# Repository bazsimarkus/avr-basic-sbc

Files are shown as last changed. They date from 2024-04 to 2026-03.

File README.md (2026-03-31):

<p align="center">
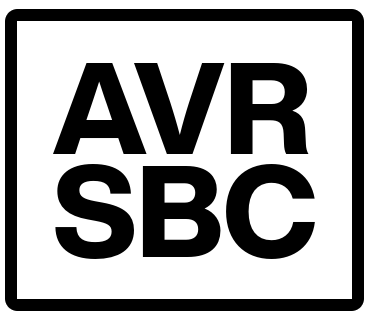
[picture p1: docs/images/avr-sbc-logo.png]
AVR-BASIC-SBC Logo
  
</p>

<h1 align="center">avr-basic-sbc</h1>

<p align="center">
  <strong>An ATmega1284P-based single board computer</strong><br>
  Composite video output &bull; PS/2 keyboard input &bull; Tiny BASIC interpreter with graphics, sound, GPIO, and serial I/O
</p>

<p align="center">
  <table align="center">
    <tr>
      <td align="center">
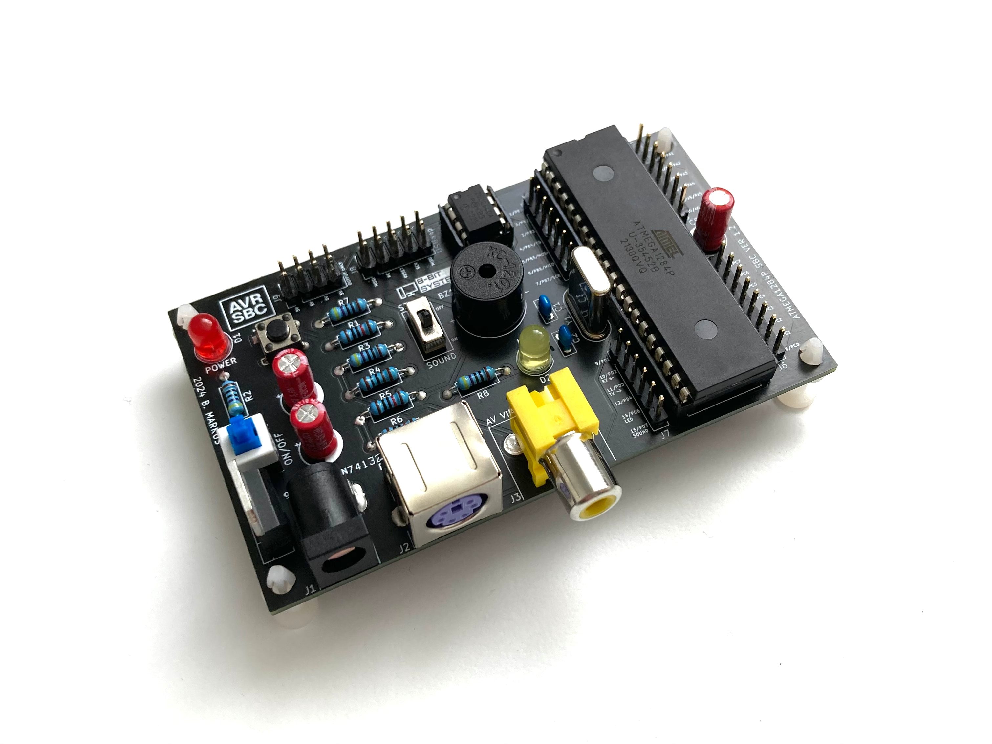
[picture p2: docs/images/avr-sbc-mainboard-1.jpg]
AVR-SBC Mainboard
        
      </td>
      <td align="center">
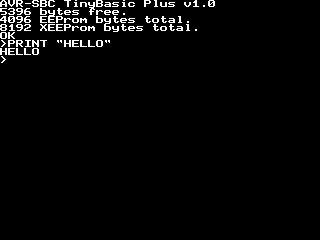
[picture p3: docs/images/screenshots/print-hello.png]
Hello World on AVR-SBC
        
      </td>
    </tr>
  </table>
</p>

---

## Table of Contents

- [Overview](#overview)
- [Features](#features)
- [Hardware](#hardware)
  - [Main Board](#main-board)
  - [Schematic](#schematic)
  - [Bill of Materials](#bill-of-materials)
  - [Pin Mapping](#pin-mapping)
- [Firmware](#firmware)
  - [Architecture](#architecture)
  - [Graphics & Video](#graphics--video)
  - [Tiny BASIC Interpreter](#tiny-basic-interpreter)
  - [Building & Flashing](#building--flashing)
- [Boomerang Shields](#boomerang-shields)
  - [Serial Boomerang Shield](#serial-boomerang-shield)
  - [Bluetooth Boomerang Shield](#bluetooth-boomerang-shield-perfboard-prototype)
  - [Seven Segment Display Extension](#seven-segment-display-extension-perfboard-prototype)
- [SBC Studio](#sbc-studio)
  - [Code Editor & Serial Upload](#code-editor--serial-upload)
  - [Bitmap Editor & Loader](#bitmap-editor--loader)
  - [MIDI to BAS Converter](#midi-to-bas-converter)
- [BASIC Examples](#basic-examples)
  - [Hello World](#hello-world)
  - [Graphics Demos](#graphics-demos)
  - [Games](#games)
  - [Sound Examples](#sound-examples)
  - [Hardware I/O Examples](#hardware-io-examples)
- [Known Limitations & Future Ideas](#known-limitations--future-ideas)
- [Personal Notes](#personal-notes)
- [Inspirations & Credits](#inspirations--credits)

---

## Overview

I always loved retrocomputing. As a kid I played around with a Commodore 64 - which I still own to this day - and I was always fascinated by the fact that computers are really just embedded systems, just nowadays unimaginably fast ones. This project grew out of that fascination.

The idea is not completely original. Many people have built similar things, and my two biggest inspirations were Jörg Wolfram's [AVR ChipBASIC](https://www.jcwolfram.de/projekte/avr/chipbasic/main.php) and Juan J. Martínez's [DAN64](https://www.usebox.net/jjm/dan64/). Neither was quite what I had in mind though - I wanted something simple to use, simple to develop for, and simple to build. A Tiny BASIC based single board computer with composite video output, a PS/2 keyboard, and some GPIO, all on a single through-hole PCB. So I decided to build my own, and here it is.

The **AVR-SBC** is an ATmega1284P-based single board computer running a Tiny BASIC interpreter. It generates a composite video signal (320×240, PAL) directly from the microcontroller, accepts input from a PS/2 keyboard, has an onboard buzzer for sound, and exposes GPIO pins for interacting with the outside world. There is also an external 25LC640 SPI EEPROM for storing programs and data - I particularly like using it to store bitmaps that can be drawn on the screen. The internal EEPROM of the ATmega1284P is available too, so a typical setup is storing a drawing program in the internal EEPROM and the actual bitmap data in the external one.

The whole thing is built with plain `avr-gcc` and `avrdude`. No Arduino framework, no dependencies - just good old C and a bit of assembly where the timing gets tight.

<p align="center">
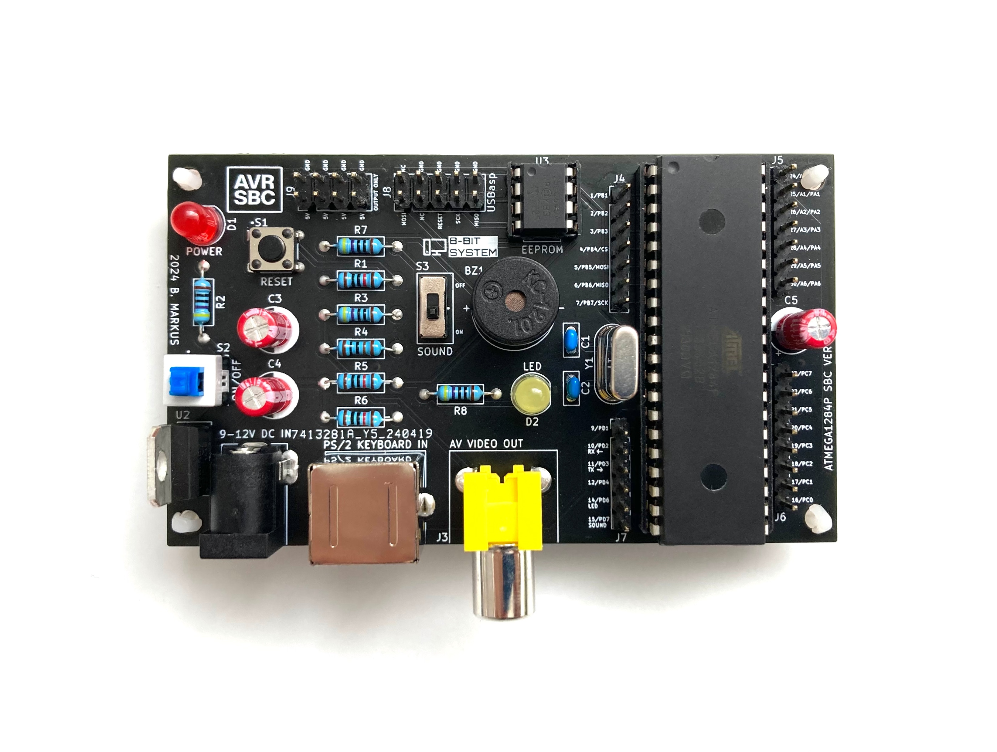
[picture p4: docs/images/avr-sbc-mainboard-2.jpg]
AVR-SBC Mainboard (alternate angle)
  
</p>

---

## Features

- **ATmega1284P** running at 16 MHz - 128 KB flash, 16 KB SRAM, 4 KB internal EEPROM
- **Composite video output** via RCA jack - 320×240 PAL, generated directly by the MCU
- **PS/2 keyboard input** - supports EN (QWERTY), DE (QWERTZ), and HU (QWERTZ) layouts, selectable at compile time
- **Tiny BASIC interpreter** - interactive prompt with 40×30 character terminal, blinking cursor, and a nice MS-DOS style 8×8 font
- **Graphics library** - pixel, line, rectangle, filled rectangle, circle, filled circle, ellipse, triangle, bitmap drawing, and more
- **Onboard piezo buzzer** - `TONE`, `TONEW`, `NOTONE` commands for playing melodies, with a slide switch to disable it
- **External 25LC640 SPI EEPROM** (8 KB) - accessible from BASIC via `XPOKE`, `XPEEK`, `XSAVE`, `XLOAD`, `XFORMAT`; great for storing bitmaps
- **Internal EEPROM** (4 KB) - accessible via `EPOKE`, `EPEEK`, `ESAVE`, `ELOAD`, `EFORMAT`
- **GPIO** - `DWRITE`, `DREAD`, `AWRITE`, `AREAD` commands using MightyCore-style pin numbering
- **UART1 serial interface** - for uploading programs from a PC via `SERLOAD`
- **Two onboard LEDs** - red power indicator, yellow user-controllable LED on PD6
- **Tactile reset button** and **power toggle switch**
- **5V regulated power** via L7805CV from a standard DC barrel jack
- **No Arduino framework** - built entirely with `avr-gcc` and `avrdude`
- **Boomerang shields** - stackable expansion boards for serial USB and Bluetooth program upload *(see [Boomerang Shields](#boomerang-shields))*
- **SBC Studio** - companion Python app for editing, uploading, bitmap conversion, and MIDI-to-BASIC conversion *(see [SBC Studio](#sbc-studio))*

---

## Hardware

### Main Board

The AVR-SBC is a fully through-hole PCB, which was a deliberate choice - it makes it easy to solder by hand and easy to modify. The board is revision **v1.2**. Versions v1.0 and v1.1 were non-working prototypes that got soldered, debugged, and eventually thrown away. The third one worked, and it has been working reliably ever since.

The heart of the board is the **ATmega1284P** in a DIP-40 socket, running off a 16 MHz HC49-U crystal. Power comes in through a standard 2.1mm DC barrel jack and is regulated to 5V by an **L7805CV** linear regulator. There are two LEDs - a red power indicator and a yellow user-controllable one on PD6. A tactile button handles reset, a toggle switch controls power, and a slide switch can disconnect the buzzer if you get tired of the beeping.

Video goes out through an RCA jack. The PS/2 keyboard connector is a right-angle Mini-DIN. There is also an external **25LC640** SPI EEPROM in a DIP-8 socket, and a 2×5 USBasp ISP programming header.

<p align="center">
  AVR-SBC Mainboard
</p>

---

### Schematic

<p align="center">
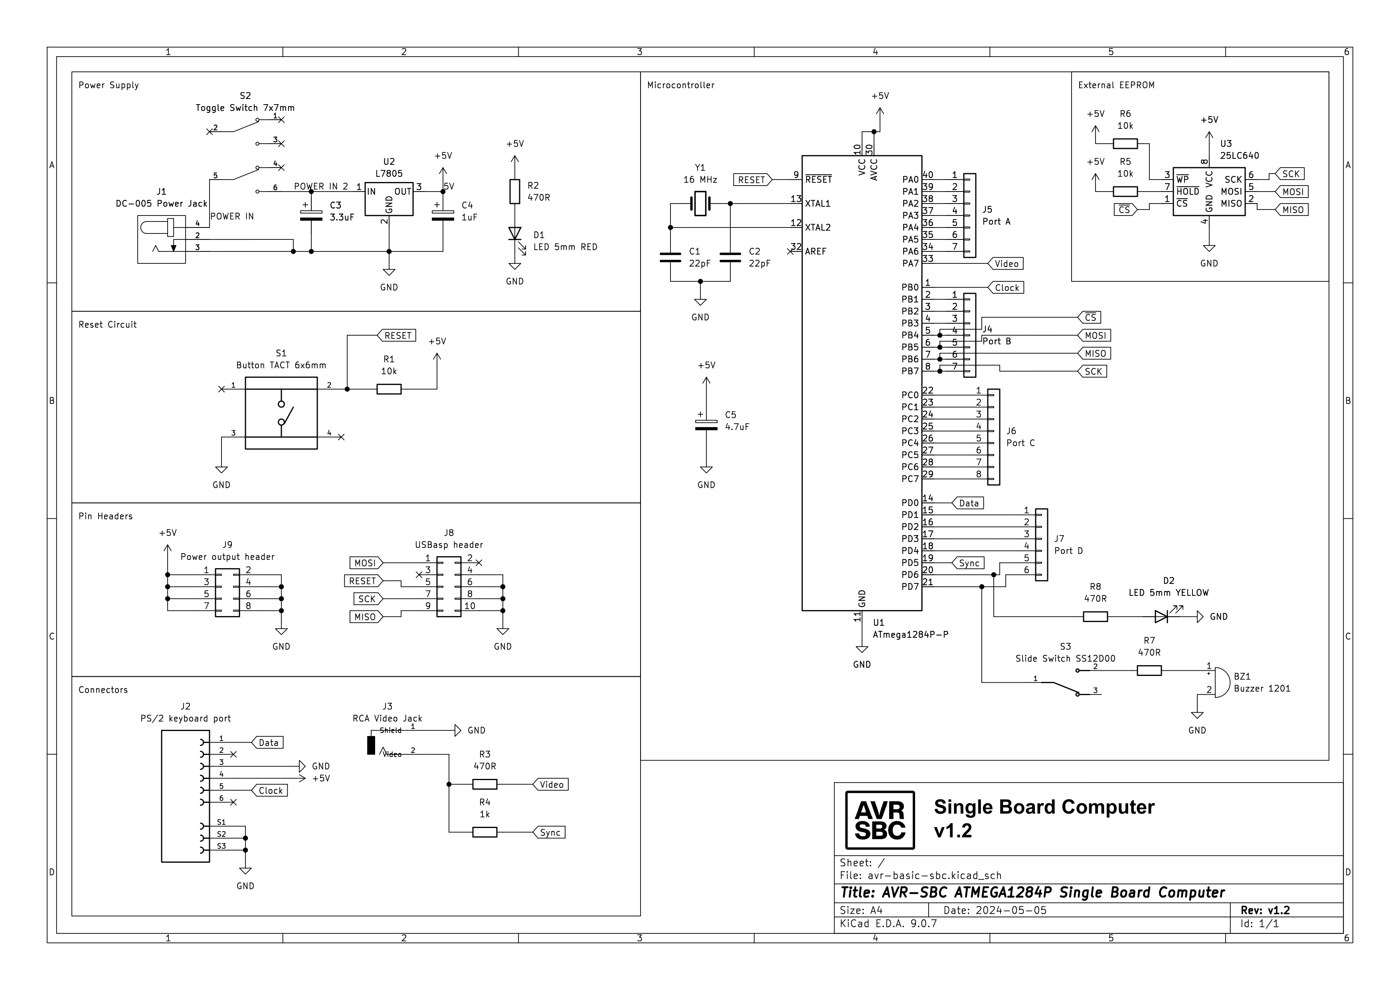
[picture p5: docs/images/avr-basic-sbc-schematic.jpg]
AVR-BASIC-SBC Schematic
  
</p>

The full KiCad project including schematic, PCB, and Gerber files is available in the `schematic/` folder.

---

### Bill of Materials

| Reference | Qty | Value / Part |
|---|-----|---|
| U1 | 1 | ATmega1284P-P (DIP-40) |
| U2 | 1 | L7805CV - 5V linear regulator (TO-220) |
| U3 | 1 | 25LC640 - SPI EEPROM 8KB (DIP-8) |
| Y1 | 1 | 16 MHz crystal (HC49-U) |
| BZ1 | 1 | Buzzer (polarized, 1201 footprint) |
| C1, C2 | 2 | 22 pF - crystal load capacitors |
| C3 | 1 | 3.3 µF electrolytic |
| C4 | 1 | 1 µF electrolytic |
| C5 | 1 | 4.7 µF electrolytic |
| D1 | 1 | LED 5mm RED - power indicator |
| D2 | 1 | LED 5mm YELLOW - user LED (PD6) |
| R1, R5, R6 | 3 | 10 kΩ |
| R2, R3, R7, R8 | 4 | 470 Ω |
| R4 | 1 | 1 kΩ |
| S1 | 1 | Tactile button 6×6mm - reset |
| S2 | 1 | Toggle switch 7×7mm - power |
| S3 | 1 | Slide switch - buzzer on/off |
| J1 | 1 | DC barrel jack 2.1mm (DC-005) |
| J2 | 1 | PS/2 keyboard connector (Mini-DIN 6) |
| J3 | 1 | RCA video jack |
| J4-J7 | 4 | Pin headers - Port B, A, C, D GPIO |
| J8 | 1 | 2×5 pin header - USBasp ISP |
| J9 | 1 | 2×4 pin header - power output |

---

### Pin Mapping

The firmware uses **MightyCore-style** pin numbering for the ATmega1284P, which is also what the BASIC `DWRITE`, `DREAD`, `AWRITE`, and `AREAD` commands expect.

| Pin | Port | Function | Available? |
|-----|---|---|---|
| 0 | PB0 | PS/2 keyboard clock | ✗ reserved |
| 1-3 | PB1-PB3 | GPIO (J4) | ✓ |
| 4-7 | PB4-PB7 | SPI - EEPROM /CS, MOSI, MISO, SCK | shared |
| 8 | PD0 | PS/2 keyboard data | ✗ reserved |
| 9 | PD1 | UART1 TX | ✓ |
| 10 | PD2 | UART1 RX | ✓ |
| 11-12 | PD3-PD4 | GPIO (J7) | ✓ |
| 13 | PD5 | Video sync output | ✗ reserved |
| 14 | PD6 | Yellow LED | ✓ |
| 15 | PD7 | Buzzer / OC2A | ✓ |
| 16-23 | PC0-PC7 | GPIO (J6) - fully free | ✓ |
| 24-30 | PA0-PA6 | GPIO (J5) - exposed on header, but see note | ⚠ see note |
| 31 | PA7 | Video data output | ✗ reserved |

> **Note on PORTA:** The high-resolution line rendering routine writes pixel data to the entire PORTA register using the AVR `OUT` instruction (1 cycle, cycle-exact timing). This means the whole port is effectively owned by the video system at runtime. The pins are physically accessible on the J5 header, but using them as GPIO will corrupt the video output. PORTC is the recommended alternative for free GPIO pins.

---

## Firmware

### Architecture

The firmware is pure C (and one assembly file), built with `avr-gcc` and flashed with `avrdude`. No Arduino framework, no HAL, no magic. Everything is wired up by hand.

The three hardware timers are each assigned a dedicated role and they all have to coexist without stepping on each other, which was honestly one of the trickier parts of getting this running:

| Timer | Role |
|---|---|
| Timer0 | 1 ms system tick (CTC mode) - used by `DELAY` and the tone duration counter |
| Timer1 | Composite video sync and scanline generation |
| Timer2 | Tone output on OC2A / PD7 - drives the buzzer via `TONE` / `TONEW` |

Memory is tight. The ATmega1284P has 16 KB of SRAM, and between the 9600-byte framebuffer (320×240 ÷ 8) and the 5500-byte BASIC program buffer, there is not much room left. It works, but there is not a lot of headroom to play with.

---

### Graphics & Video

The video output is the part I am most proud of - and the part that gave me the most trouble.

I originally used the Arduino TVout library like most similar projects do. It works, but the resolution is limited and I never really liked how it looked. I wanted 320×240, so I decided to write my own graphics library. That turned out to be a good decision, but it had consequences.

The line rendering function - `render_scanline()` in `render_line.S` - has to output one pixel every single clock cycle to hit 320 pixels per line at 16 MHz. There is simply no way to do that in C. Even a tight loop has overhead that breaks the timing. So I wrote it in AVR assembly, fully unrolled, 40 bytes × 8 bits per byte, outputting each pixel with a single `OUT` instruction directly to PORTA. No loop, no branches, just 320 consecutive `OUT` and `LSL` pairs.

The downside is that `OUT` writes to the entire port at once. That means **PORTA is permanently reserved** by the video system at runtime - the pins are physically on the J5 header, but you cannot use them as GPIO without corrupting the video output. PORTC has 8 fully free pins (J6) and is the recommended alternative. I never found a way around this limitation at 320×240, so I left it as-is. Ideas are welcome.

The graphics library (`graphics.c`) supports:

- Pixels, lines (Bresenham), horizontal and vertical lines
- Rectangles, filled rectangles, rounded rectangles
- Circles, filled circles, ellipses, filled ellipses
- Triangles, filled triangles
- Bitmap drawing from RAM or PROGMEM
- 8×8 font character rendering (MS-DOS style)
- Three draw modes: `SET`, `CLEAR`, `XOR`

The text terminal layer (`text.c`) sits on top of the graphics library and provides a 40×30 character terminal with scrolling, wrap-around, and a blinking cursor.

---

### Tiny BASIC Interpreter

The firmware is almost a direct port of **TinyBASIC**, originally written by Gordon Brandly as *68000 Tiny Basic*, then ported to C by Michael Field as *Arduino Basic*, and further developed by Scott Lawrence as *TinyBasicPlus*. I adapted it to be fully AVR C based - no Arduino framework anywhere.

On startup, the board displays a splash screen with the firmware version and available memory, then drops into the interactive `>` prompt.

<p align="center">
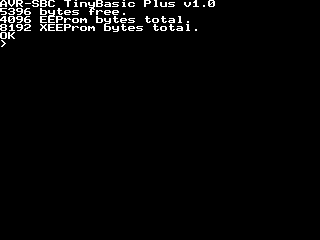
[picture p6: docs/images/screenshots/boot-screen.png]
AVR-SBC Boot Screen
  
</p>

The BASIC command set includes everything you would expect, plus a bunch of hardware-specific extensions:

#### Core Commands

| Command | Description | Example |
|---|---|---|
| `PRINT expr, expr, ...` | Prints expressions (strings or numbers) to the screen. Items separated by `,`. End with `;` to suppress newline. `?` is a shorthand alias. | `PRINT "HELLO", X` |
| `INPUT var` | Prompts the user with `?` and reads a numeric value into variable `var` (A-Z). | `INPUT A` |
| `LET var = expr` | Assigns the value of an expression to a variable (A-Z). The `LET` keyword is optional. | `LET X = 42` or `X = 42` |
| `IF expr THEN statement` | Evaluates expression; if non-zero, executes the statement after `THEN`. `THEN` is optional. Relational operators: `=`, `<>`, `!=`, `<`, `>`, `<=`, `>=`. | `IF X > 10 THEN PRINT "BIG"` |
| `GOTO expr` | Jumps to the line number given by the expression. | `GOTO 100` |
| `GOSUB expr` | Calls the subroutine at the given line number, pushing a return address onto the stack. | `GOSUB 500` |
| `RETURN` | Returns from the most recent `GOSUB` call. | `RETURN` |
| `FOR var = expr TO expr [STEP expr]` | Begins a counting loop. Variable iterates from start to end value. `STEP` defaults to 1 if omitted. | `FOR I = 1 TO 10 STEP 2` |
| `NEXT var` | Advances the `FOR` loop variable and branches back if the loop has not finished. | `NEXT I` |
| `END` | Stops program execution and returns to the prompt. | `END` |
| `STOP` | Same as `END` - stops program execution. | `STOP` |
| `REM text` | Comment line; everything after `REM` (or `'`) is ignored. | `REM THIS IS A COMMENT` |

#### Program Management

| Command | Description | Example |
|---|---|---|
| `RUN` | Executes the stored program from the first line. | `RUN` |
| `LIST [linenum]` | Lists the stored program. If a line number is given, listing starts from that line. | `LIST` or `LIST 100` |
| `NEW` | Erases the stored program from memory. | `NEW` |
| `LOAD` | Loads a program (stub - unimplemented on this platform). | `LOAD` |
| `SAVE` | Saves a program (stub - unimplemented on this platform). | `SAVE` |
| `CHAIN` | Loads a program and auto-runs it after loading (stub - unimplemented on this platform). | `CHAIN` |
| `MEM` | Prints the number of free BASIC program bytes and EEPROM usage statistics. | `MEM` |
| `BYE` | Exits the BASIC interpreter. | `BYE` |

#### GPIO

| Command | Description | Example |
|---|---|---|
| `DWRITE pin, value` | Sets a digital GPIO pin HIGH or LOW. Value can be `HIGH`/`HI`, `LOW`/`LO`, or a numeric expression (0/1). Uses MightyCore pin numbering. | `DWRITE 14, 1` |
| `AWRITE pin, value` | Writes an analog (PWM) value to a GPIO pin. Same syntax as `DWRITE`. | `AWRITE 14, 128` |
| `DREAD(pin)` | Function - reads a digital pin and returns 1 (HIGH) or 0 (LOW). Enables the internal pull-up resistor. | `X = DREAD(16)` |
| `AREAD(pin)` | Function - reads an analog value (0-1023) from an ADC pin (pins 24-30 only). | `X = AREAD(24)` |

#### Graphics

| Command | Description | Example |
|---|---|---|
| `DRAWPIX x, y, c` | Draws a single pixel at (x, y) with draw mode `c` (0=clear, 1=set, 2=xor). | `DRAWPIX 160, 120, 1` |
| `DRAWLINE x0, y0, x1, y1, c` | Draws a line from (x0, y0) to (x1, y1) with draw mode `c`. | `DRAWLINE 0, 0, 319, 239, 1` |
| `DRAWRECT x, y, w, h, c, f` | Draws a rectangle at (x, y) with width `w` and height `h`. Outline uses draw mode `c`, fill uses draw mode `f`. Use -1 for `f` to draw outline only. | `DRAWRECT 10, 10, 50, 30, 1, 1` |
| `DRAWCIRC cx, cy, r, c, f` | Draws a circle centered at (cx, cy) with radius `r`. Outline uses draw mode `c`, fill uses draw mode `f`. Use -1 for `f` to draw outline only. | `DRAWCIRC 160, 120, 40, 1, 0` |
| `DRAWCHAR x, y, char` | Draws a single 8×8 character at pixel position (x, y). The character is the literal next character in the source. | `DRAWCHAR 10, 10, A` |
| `GETPIX x, y` | Prints the pixel value (0 or 1) at position (x, y) to the screen. | `GETPIX 100, 50` |
| `CLS` | Clears the entire screen and resets the text cursor. | `CLS` |

#### Sound

| Command | Description | Example |
|---|---|---|
| `TONE freq, duration` | Starts playing a tone at `freq` Hz for `duration` ms on the buzzer. Execution continues immediately. | `TONE 440, 500` |
| `TONEW freq, duration` | Plays a tone at `freq` Hz for `duration` ms and **waits** until the tone finishes before continuing. | `TONEW 440, 500` |
| `NOTONE` | Immediately stops any tone currently playing. | `NOTONE` |

#### Timing

| Command | Description | Example |
|---|---|---|
| `DELAY expr` | Pauses execution for the given number of milliseconds. Breakable with ESC or Ctrl-C. | `DELAY 1000` |

#### Internal EEPROM (4 KB)

| Command | Description | Example |
|---|---|---|
| `ESAVE` | Saves the current program to internal EEPROM. | `ESAVE` |
| `ELOAD` | Loads a program from internal EEPROM into RAM. | `ELOAD` |
| `ELIST` | Lists the contents of the internal EEPROM to the screen. | `ELIST` |
| `EFORMAT` | Erases the entire internal EEPROM (fills with zeros). | `EFORMAT` |
| `EPOKE value, addr` | Writes `value` (byte) to internal EEPROM at address `addr`. | `EPOKE 65, 0` |
| `EPEEK var, addr` | Reads a byte from internal EEPROM at address `addr` into variable `var` (A-Z). | `EPEEK A, 0` |

#### External EEPROM (8 KB - 25LC640)

| Command | Description | Example |
|---|---|---|
| `XSAVE` | Saves the current program to external SPI EEPROM. | `XSAVE` |
| `XLOAD` | Loads a program from external EEPROM into RAM. | `XLOAD` |
| `XLIST` | Lists the contents of the external EEPROM to the screen. | `XLIST` |
| `XFORMAT` | Erases the entire external EEPROM (fills with zeros). | `XFORMAT` |
| `XPOKE value, addr` | Writes `value` (byte) to external EEPROM at address `addr`. | `XPOKE 65, 0` |
| `XPEEK var, addr` | Reads a byte from external EEPROM at address `addr` into variable `var` (A-Z). | `XPEEK A, 0` |

#### Serial (UART1)

| Command | Description | Example |
|---|---|---|
| `SEROPEN` | Opens UART1 at 9600 baud for serial communication. | `SEROPEN` |
| `SERCLOSE` | Closes UART1. | `SERCLOSE` |
| `SERPRINT expr, expr, ...` | Sends expressions (strings or numbers) over UART1. Same syntax as `PRINT`. | `SERPRINT "HELLO"` |
| `SERREAD` | Reads and displays characters from UART1 until a newline or 5-second timeout. | `SERREAD` |
| `SERLOAD` | Loads a BASIC program from UART1 into RAM (used for PC upload via SBC Studio). | `SERLOAD` |

#### Miscellaneous

| Command | Description | Example |
|---|---|---|
| `INKEY var` | Non-blocking keyboard read. Stores the ASCII value of the pressed key into variable `var` (A-Z), or 0 if no key is pressed. | `INKEY K` |
| `RSEED expr` | Seeds the random number generator with the given value. | `RSEED 42` |
| `POKE addr, value` | Writes `value` (byte) to RAM address `addr` within the BASIC memory buffer. | `POKE 0, 65` |
| `PEEK(addr)` | Function - reads a byte from RAM address `addr` within the BASIC memory buffer. | `X = PEEK(0)` |
| `ABS(expr)` | Function - returns the absolute value of the expression. | `X = ABS(-5)` |
| `RND(expr)` | Function - returns a random integer from 0 to `expr`-1. | `X = RND(100)` |

#### Operators

| Operator | Description |
|---|---|
| `+`, `-`, `*`, `/` | Arithmetic: addition, subtraction, multiplication, integer division |
| `=`, `<>`, `!=`, `<`, `>`, `<=`, `>=` | Relational operators (return 1 if true, 0 if false) |
| `-expr` | Unary negation |
| `(expr)` | Parentheses for grouping |

#### Notes:

- Line numbers are required for stored programs (e.g. `10`, `20`, `30`). Direct commands can be typed without a line number.
- Variables: single uppercase letters `A`-`Z`, 16-bit signed integers (-32768 to 32767)
- Strings in double or single quotes: `"HELLO"` or `'HELLO'`
- Multiple statements per line separated by `:` - e.g. `10 A=1 : B=2 : PRINT A+B`
- Screen resolution: 320×240 pixels (x: 0-319, y: 0-239)
- Program RAM: 5500 bytes total
- Break execution at any time with **ESC** or **Ctrl-C**

---

### Building & Flashing

**Requirements:** `avr-gcc`, `avr-libc`, `avrdude`, and `make`. On Windows, [WinAVR](https://winavr.sourceforge.net/) or Microchip Studio works fine. On Linux/macOS, install from your package manager.

```bash
# Build with default US/English keyboard layout
make

# Build with German QWERTZ layout
make KB_LAYOUT=DE

# Build with Hungarian QWERTZ layout
make KB_LAYOUT=HU

# Flash via USBasp programmer
make flash

# Show flash / SRAM / EEPROM usage
make size
```

The Makefile also exposes feature flags if you want to disable subsystems:

```bash
# Build without tone support (frees Timer2)
make FEAT_TONES=0

# Build without external EEPROM support
make FEAT_XEEPROM=0
```

**Flashing** is done via the 2×5 USBasp ISP header (J8). One important thing to be aware of: **the 5V pin on the ISP header is not connected**. The board must be powered through the DC barrel jack before you can flash it. This was a conscious decision on v1.2 to avoid back-feeding the microcontroller through the programmer.

The default programmer in the Makefile is `usbasp`. If you use something else, change the `-c usbasp` flag in the `flash` target accordingly.

---

## Boomerang Shields

After a while, connecting an FTDI USB-serial cable to PD2 and PD3 every time I wanted to upload a program got old really fast. So I opened KiCad again and designed a small stackable expansion board - the **Boomerang Shield**.

Why boomerang? Because of the shape. It has cutouts for the crystal and capacitors, and it follows the contour of the pin headers on the main board. I didn't mean for it to look like a boomerang, it just happened that way. I didn't want to redesign it - this is already the third revision of the main board - so the name stuck.

The shields use the same 2.54mm pin headers as the main board and stack directly on top. Pin headers are also broken out on the shield itself so GPIO access is not lost.

---

### Serial Boomerang Shield

<p align="center">
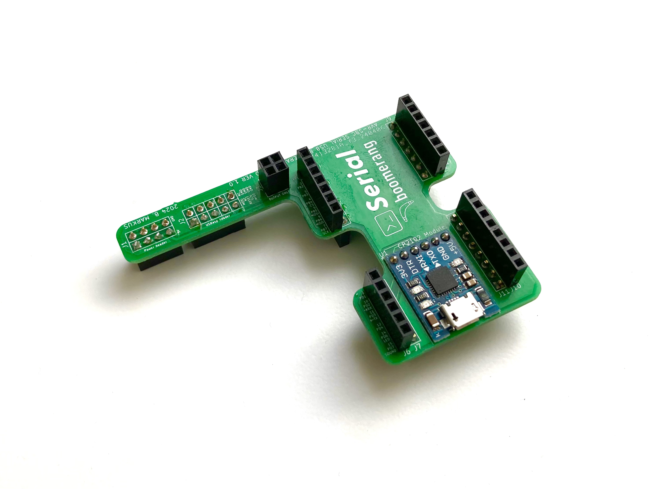
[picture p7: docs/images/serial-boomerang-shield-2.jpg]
Serial Boomerang Shield (bottom view)
  
</p>

The serial boomerang shield is the official one. It carries a **CP2102 USB-to-serial bridge module**, connects to UART1 (PD2/PD3) of the AVR-SBC, and exposes a micro-USB connector. That's it - but now I can just leave it sitting on top of the board and upload programs with a single cable. Much better.

<p align="center">
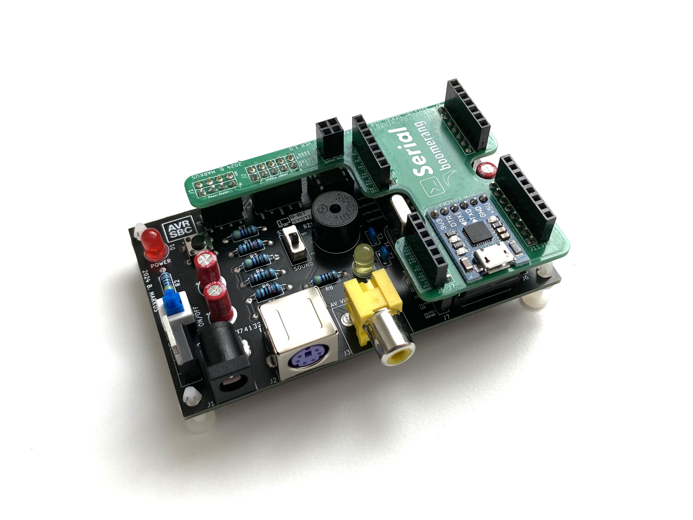
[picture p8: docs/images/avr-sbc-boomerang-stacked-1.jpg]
Serial Boomerang Shield stacked on AVR-SBC
  
</p>

The KiCad project, schematic, and Gerber files for the serial boomerang shield are in the `boomerang-shields/serial-boomerang-shield/` folder. There is also an **empty boomerang shield template** in `boomerang-shields/empty-boomerang-shield-template/` if you want to design your own expansion.

<p align="center">
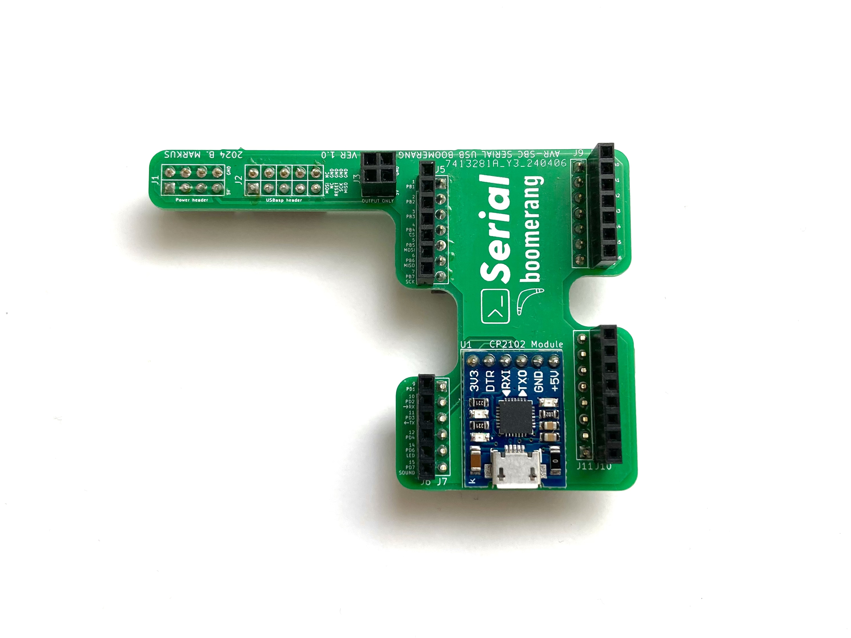
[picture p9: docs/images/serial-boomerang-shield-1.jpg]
Serial Boomerang Shield
  
</p>

---

### Bluetooth Boomerang Shield *(perfboard prototype)*

Once I had the serial shield working, I started thinking about what else could plug into the same spot. The CP2102 module and an **HC-06 Bluetooth Classic module** have a very similar pinout - both are essentially a UART bridge. So I quickly wired one up on a perfboard with the same pin header footprint as the serial shield, plugged it in, and it worked.

<p align="center">
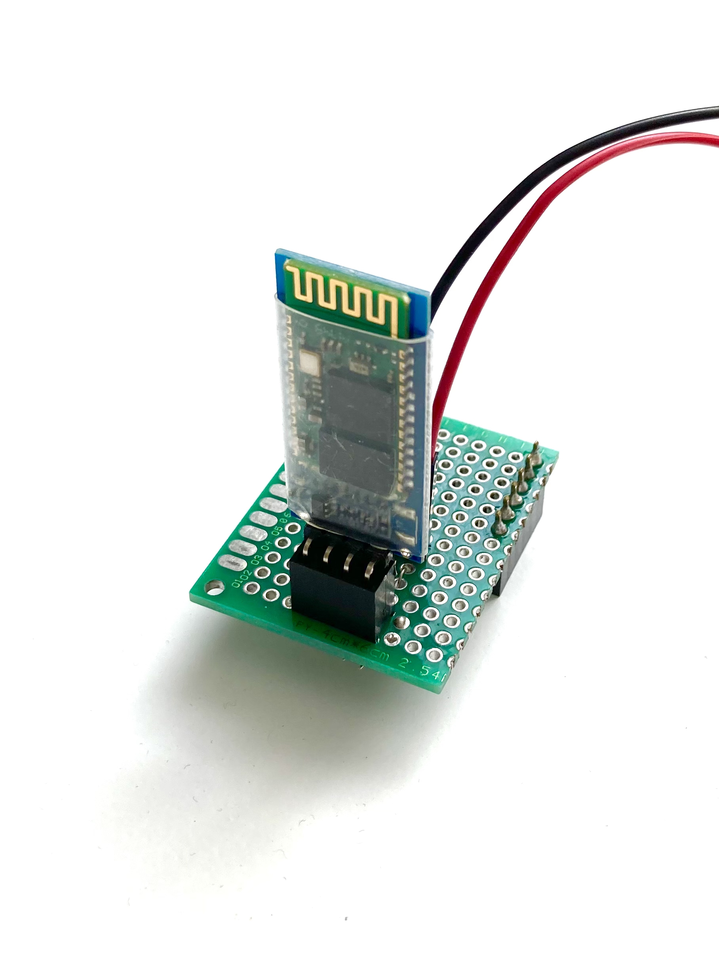
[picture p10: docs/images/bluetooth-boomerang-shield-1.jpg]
Bluetooth Boomerang Shield (perfboard prototype)
  
</p>

When the HC-06 is paired with a PC, it shows up as a virtual COM port via Bluetooth Classic SPP - exactly the same as the USB cable. That means I can upload BASIC programs to the AVR-SBC completely wirelessly. Which is, honestly, pretty amazing for a board built around an 8-bit microcontroller.

There is no official PCB design for the Bluetooth boomerang yet - it lives on a perfboard prototype for now. If I ever design it properly, I would probably use a better module, something like a Würth Elektronik Proteus-IV, a Skoll-I, or an ESP32-based module.

---

### Seven Segment Display Extension *(perfboard prototype)*

I also soldered together a small perfboard circuit with a **seven segment display** that stacks on top of the boomerang shield.

<p align="center">
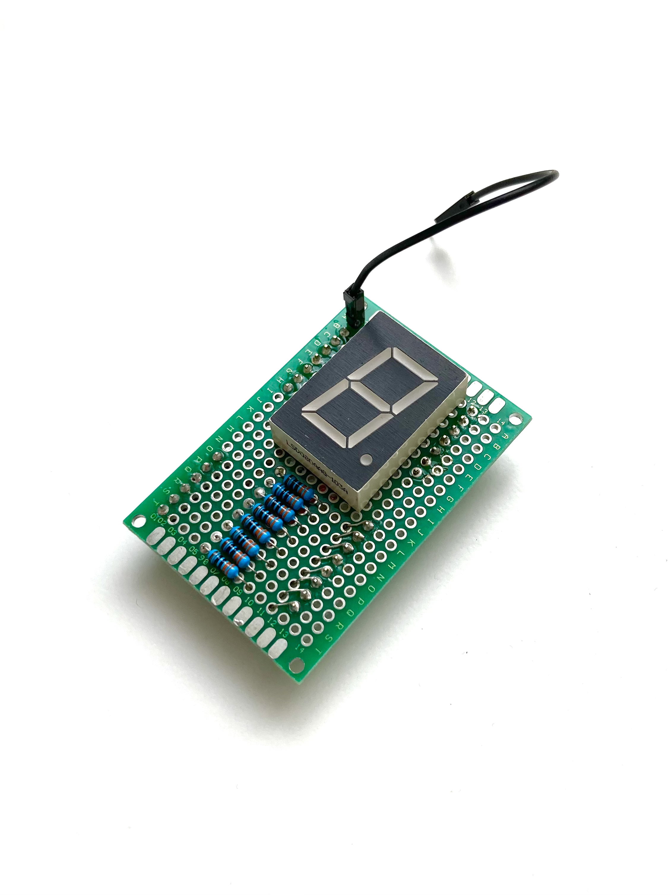
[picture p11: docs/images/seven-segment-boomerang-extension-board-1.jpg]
Seven Segment Extension Board
  
</p>

So at one point I had three layers: AVR-SBC → Serial Boomerang Shield → Seven Segment Extension. There is a BASIC example for it in the `examples/` folder.

<p align="center">
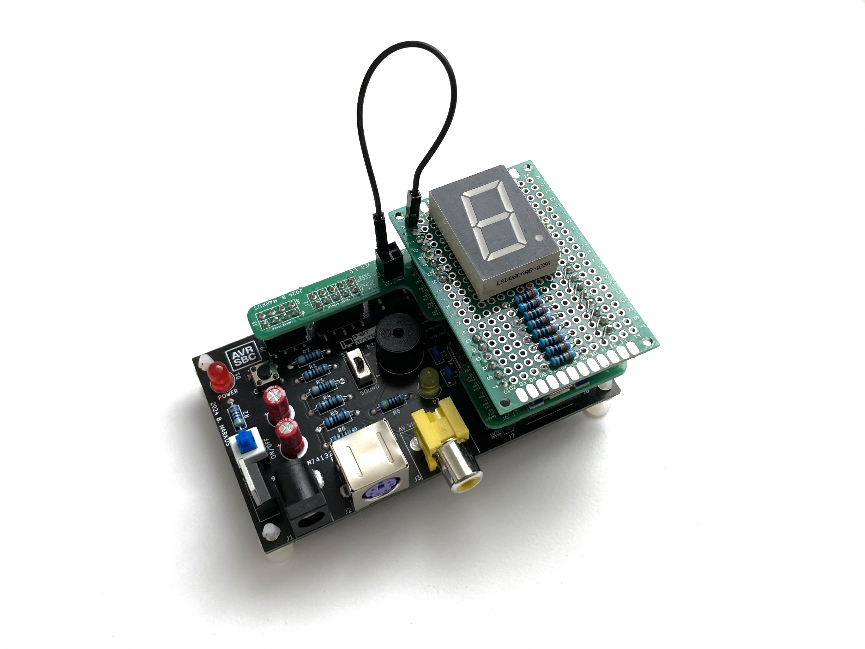
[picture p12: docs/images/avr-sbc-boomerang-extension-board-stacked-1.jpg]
All three boards stacked
  
</p>

Like the Bluetooth shield, this one never got an official PCB design. It remains a perfboard prototype.

---

## SBC Studio

SBC Studio is a companion Python application for the AVR-SBC. It started as a simple serial uploader - basically just a way to type programs into the board really fast over UART1 without having to sit at a PS/2 keyboard. Over time it grew into something more, so I gave it a proper name.

<p align="center">
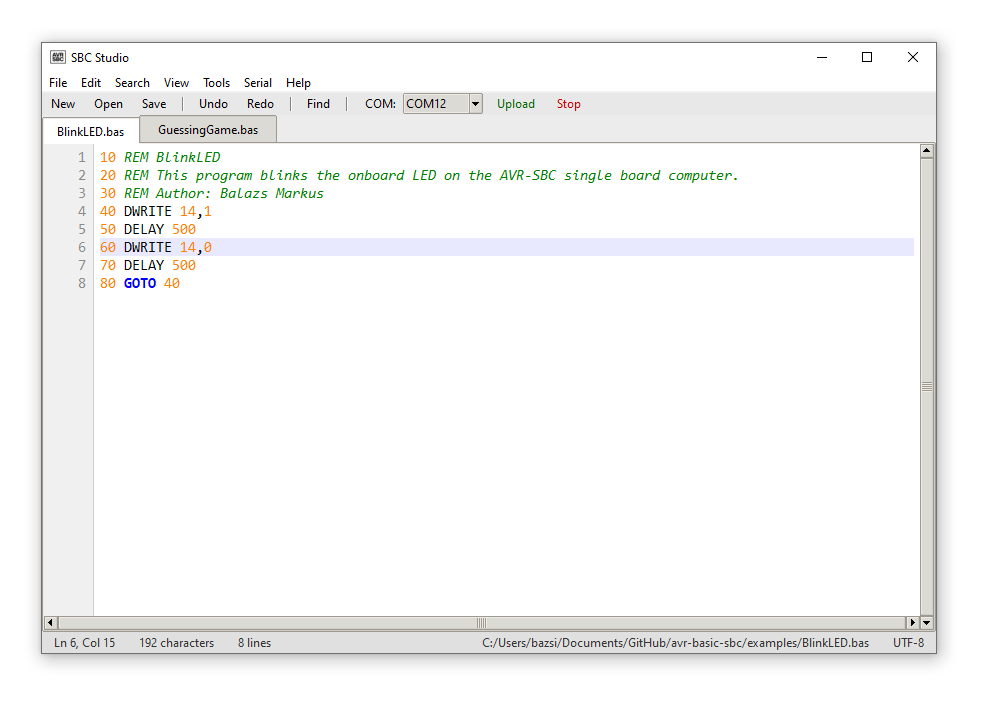
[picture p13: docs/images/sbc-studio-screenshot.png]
SBC Studio screenshot
  
</p>

It requires Python 3 with `pyserial`. The bitmap tools also need `Pillow`, and the MIDI converter needs `pretty_midi`. Everything else is standard library.

```bash
pip install pyserial Pillow pretty_midi
python sbc-studio.py
```

The source is in `pc-tools/sbc-studio/`.

---

### Code Editor & Serial Upload

The main window is a lightweight `.bas` file editor with syntax highlighting, line numbers, tab support, find & replace, and undo/redo. It is nothing fancy, but it is comfortable enough for writing and editing Tiny BASIC programs.

The serial upload works by opening UART1 at 9600 baud and sending the program character by character - essentially simulating someone typing it in at the `>` prompt, just very fast. To upload, select your COM port from the toolbar, open or write a `.bas` file, and hit upload. The board receives it line by line exactly as if you had typed it yourself.

The keyboard layout for the PS/2 side (EN/DE/HU) is selected at firmware compile time, but the upload always goes through serial so the layout doesn't matter there.

---

### Bitmap Editor & Loader

This was a fun one to build. The **Bitmap Editor** takes any image file and converts it to a 128×64 monochrome bitmap suitable for the AVR-SBC screen. It has options for scaling, centering, dithering (Floyd-Steinberg), threshold control, rotation, flip, and background colour. The output is a standard 1-bit `.bmp` file.

The **Bitmap Loader** then uploads that `.bmp` to the AVR-SBC's external 25LC640 EEPROM via serial, using `XPOKE` commands split into batches. Once uploaded, a small BASIC program reads the bitmap back out with `XPEEK` and draws it pixel by pixel with `DRAWPIX`.

<p align="center">
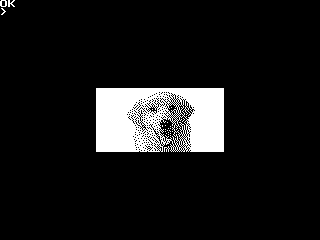
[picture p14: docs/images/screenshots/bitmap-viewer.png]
Bitmap viewer running on the AVR-SBC
  
</p>

I included two examples in `pc-tools/sbc-studio/sbc-studio-output/bitmap-editor/` - a photo of our dog and a flower.

The reason I like this so much is that the external EEPROM fits a 128×64 bitmap very comfortably, and you never have to take the chip out of the socket to reprogram it. Everything goes over serial.

---

### MIDI to BAS Converter

At some point I realised that the `TONEW` command - which plays a tone at a given frequency and waits for it to finish - maps almost perfectly onto MIDI note data. So I built a converter that takes a single-track `.mid` file, extracts the notes, calculates frequencies and durations, and outputs a `.bas` file full of `TONEW` and `DELAY` statements that the AVR-SBC can play on its onboard buzzer.

The output is capped at around 5300 bytes to fit the BASIC program buffer. It is not going to replace a proper audio system, but hearing Für Elise come out of a piezo buzzer on a board you built yourself is genuinely satisfying. Two examples are included in `pc-tools/sbc-studio/sbc-studio-output/midi-to-bas-converter/` - Für Elise and Ode to Joy.

---

## BASIC Examples

Once the board was up and running I could finally sit down and actually write some programs for it in Tiny BASIC. The examples are all in the `examples/` folder. They cover a bit of everything - games, graphics demos, sound, and hardware I/O.

All of them can be typed in at the `>` prompt directly, or uploaded from a PC using SBC Studio.

---

### Hello World

The simplest possible start. The `PRINT` command outputs text to the screen.

```basic
PRINT "HELLO"
```

<p align="center">
  Hello World on AVR-SBC
</p>

---

### Graphics Demos

The graphics library makes it easy to draw shapes directly from BASIC. These examples show off what the 320×240 display can do.

| File | Description |
|---|---|
| `ConcentricCircles.bas` | Draws concentric circles filling the screen |
| `RandomRectangles.bas` | Fills the screen with randomly placed rectangles |
| `Spirograph.bas` | Spirograph-style pattern using lines and loops |
| `StarField.bas` | Scrolling star field effect |
| `BouncingBall.bas` | A ball bouncing around the screen |

<p align="center">
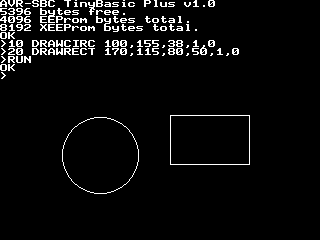
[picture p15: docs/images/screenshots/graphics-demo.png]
Graphics demo running on AVR-SBC
  
</p>

---

### Games

A few simple games that show off keyboard input, random numbers, and the graphics commands together.

| File | Description |
|---|---|
| `EatTheTargets.bas` | Move a cursor around the screen and eat targets |
| `GuessTheNumber.bas` | Classic guess the number game with hints |
| `SlotMachine.bas` | An ASCII slot machine |

---

### Sound Examples

These use the `TONE` and `TONEW` commands to play melodies on the onboard buzzer. The MIDI converter in SBC Studio was used to generate the two classical pieces.

| File | Description |
|---|---|
| `CMajorPiano.bas` | Plays a C major scale using the keyboard |
| `MelodyPlayer.bas` | A simple melody player |
| `furelise.bas` *(generated)* | Für Elise - in `pc-tools/sbc-studio/sbc-studio-output/midi-to-bas-converter/` |
| `odetojoy.bas` *(generated)* | Ode to Joy - in `pc-tools/sbc-studio/sbc-studio-output/midi-to-bas-converter/` |

---

### Hardware I/O Examples

These examples interact with the GPIO pins and show how `DWRITE`, `DREAD`, and the EEPROM commands work in practice.

| File | Description |
|---|---|
| `BlinkLED.bas` | Blinks the onboard yellow LED on PD6 using `DWRITE` |
| `SevenSegmentDisplay.bas` | Drives a seven segment display connected to PORTC |

<p align="center">
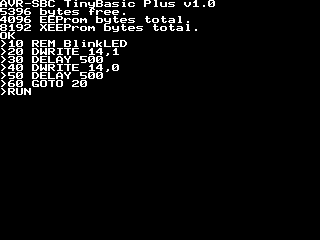
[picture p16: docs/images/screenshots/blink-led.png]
Blink LED example running on AVR-SBC
  
</p>

---

## Known Limitations & Future Ideas

The board works, and it works reliably. But it is not perfect, and I know exactly where the rough edges are.

---

### Hardware

**Decoupling capacitors** - when I designed the board I was quite casual with component choices, and I skipped the per-chip decoupling capacitors. There are bulk capacitors for the microcontroller and the L7805CV, but they are not following the reference design. If I were to redesign the board I would definitely add proper decoupling caps on every supply pin.

**No reverse polarity protection** - the DC input has no protection diode. Plugging in the barrel jack the wrong way around will likely kill the board. A simple series diode or a P-channel MOSFET would fix this.

**No Schottky diode on the ISP header** - to prevent back-feeding the microcontroller through the programmer's VCC pin, I simply left the 5V pin on the ISP header unconnected. It works, but a proper Schottky diode would be a cleaner solution. As it stands, the board must always be powered through the DC barrel jack when programming.

**PORTA reserved by the video system** - as described in the Firmware section, the cycle-exact line rendering routine writes to the entire PORTA register using the AVR `OUT` instruction. This means PA0-PA6 cannot be used as GPIO without corrupting the video output, even though the pins are physically accessible on the J5 header. Getting 320×240 resolution with proper timing while also making PORTA available as GPIO is an unsolved problem for this project. If you have an idea, I would love to hear it.

---

### Software & Features

**Boomerang shields without official PCBs** - the Bluetooth boomerang and the seven segment extension board are both perfboard prototypes. They work great but there are no KiCad files for them. At some point I would like to design proper PCBs for both - and when I do, I would probably swap the HC-06 for something more modern, like a Würth Elektronik Proteus-IV, a Skoll-I, or an ESP32-based module.

**Single-track MIDI only** - the MIDI to BAS converter in SBC Studio only handles single-track MIDI files. Multi-track files are not supported, which rules out a lot of MIDI content. Since the buzzer is monophonic anyway this is not a huge loss, but smarter track selection would be a nice improvement.

**Auto-run from EEPROM** - the firmware supports an `ENABLE_EAUTORUN` flag that automatically runs the program stored in internal EEPROM on boot, without showing the `>` prompt first. This is disabled by default but could be useful for standalone appliance-style deployments.

---

## Personal Notes

I started this project many years ago, then stopped, then restarted, then had a long pause. Many versions of KiCad were released in the meantime. AI systems started developing and becoming more and more advanced. And this project was still just there, waiting on a shelf somewhere between the other unfinished things. But occasionally when I came back to it, it made me very happy and I found it genuinely challenging.

Before this project I was usually defaulting to just using the Arduino framework - like the TVout-based firmware also did, and like many similar projects still do. But during this project I realized that with the power of real C and assembly you can get much further. Writing the line renderer in assembly, getting the timing right across three timers, squeezing everything into 16 KB of SRAM - none of that would have happened if I had stayed in Arduino land. So it was definitely a nice learning experience about myself too. Now there is no going back. Even the simplest things I do in low level C, and I have become really interested in assembly as well.

I am glad I have this project. I can't wait to see what the future brings with it - I am sure it will be exciting. And knowing myself, I will probably abandon it for a while again, and then one day come back and find something new to add. The hardware stays the same.

---

## Inspirations & Credits

### Inspiration Projects

This project would not exist without these two:

- **Jörg Wolfram** - [AVR ChipBASIC](https://www.jcwolfram.de/projekte/avr/chipbasic/main.php)
  The project that first showed me this kind of thing was possible on an AVR microcontroller.

- **Juan J. Martínez** - [DAN64](https://www.usebox.net/jjm/dan64/)
  A beautifully executed AVR-based home computer that was a big influence on the direction of this project.

---

### Tiny BASIC Lineage

The firmware interpreter is based on a long chain of ports and adaptations:

- **Gordon Brandly** - original *68000 Tiny Basic*
- **Michael Field** - ported to C as *Arduino Basic*
- **Scott Lawrence** - extended and maintained as [TinyBasicPlus](https://github.com/BleuLlama/TinyBasicPlus)

The AVR-SBC version is a bare-metal port of TinyBasicPlus, adapted for the ATmega1284P with no Arduino framework and extended with graphics, sound, EEPROM, and serial commands.

---

### Tools & Libraries

- [avr-gcc](https://gcc.gnu.org/wiki/avr-gcc) & [avr-libc](https://avr-libc.nongnu.org/) - the toolchain
- [avrdude](https://github.com/avrdudes/avrdude) - flashing utility
- [KiCad](https://www.kicad.org/) - schematic and PCB design
- [Python](https://www.python.org/) / [pyserial](https://github.com/pyserial/pyserial) / [Pillow](https://python-pillow.org/) / [pretty_midi](https://github.com/craffel/pretty-midi) - SBC Studio dependencies

---

<p align="center">
  AVR-BASIC-SBC
  <br>
  <em>Built with ❤️ and an 8-bit microcontroller</em>
</p>

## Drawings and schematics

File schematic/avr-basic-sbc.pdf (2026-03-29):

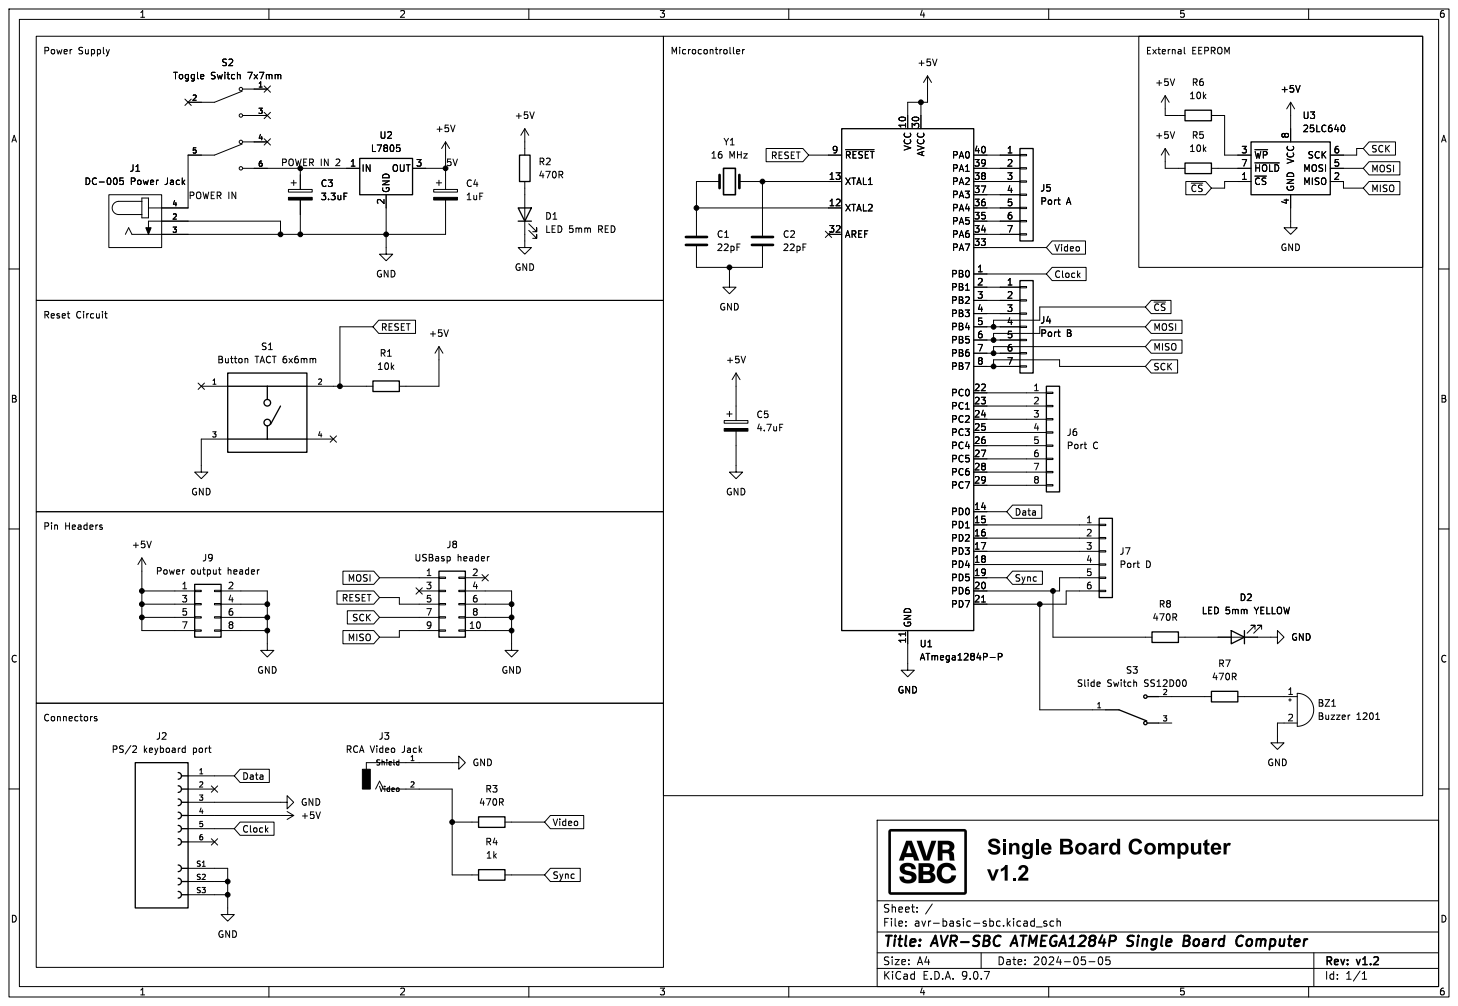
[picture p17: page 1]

Reset Circuit Power Supply

~{CS} MOSI POWER IN 2 POWER IN

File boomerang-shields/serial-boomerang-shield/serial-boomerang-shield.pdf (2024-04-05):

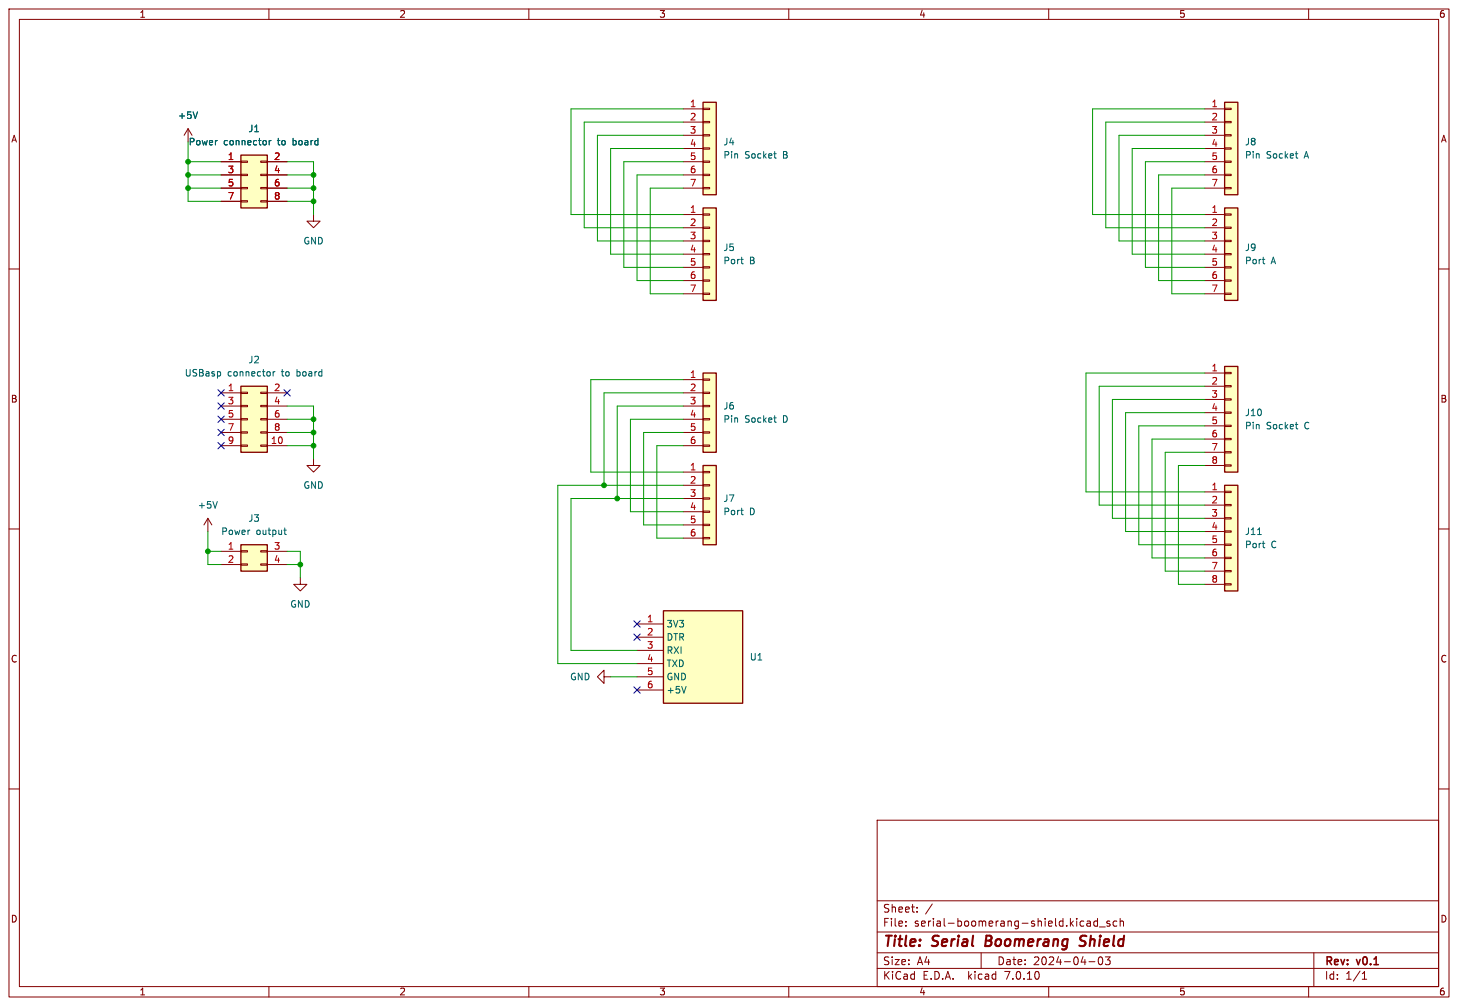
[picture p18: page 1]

File: serial-boomerang-shield.kicad_sch Sheet: /
Id: 1/1 Title: Serial Boomerang Shield

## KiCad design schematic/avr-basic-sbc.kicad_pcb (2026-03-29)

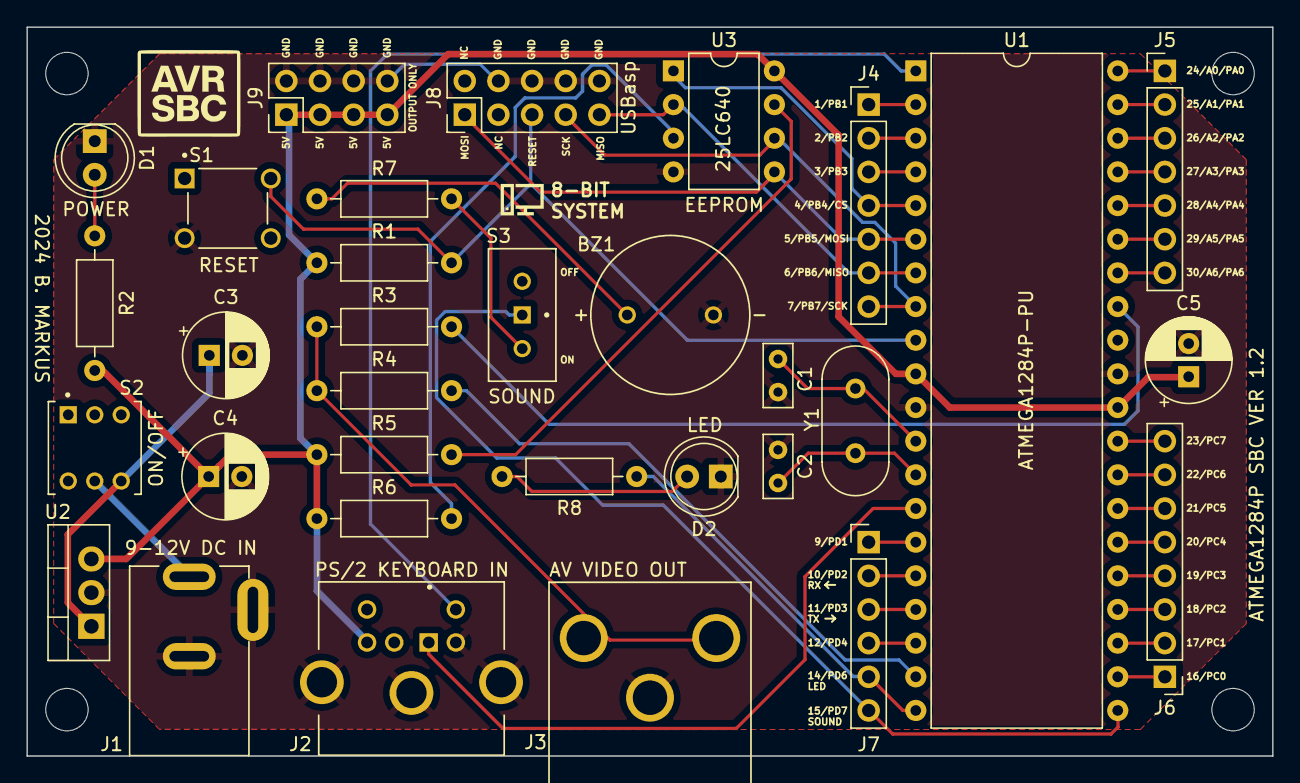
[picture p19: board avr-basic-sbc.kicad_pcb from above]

Board: 2 copper layers, 94.0 x 55.0 mm, 38 parts (0 on the bottom side), 46 nets.

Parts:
BZ1: Buzzer 1201
C1, C2: 22pF; C_Rect_L4.6mm_W2.0mm_P2.50mm_MKS02_FKP02
C3: 0.33uF; CP_Radial_D6.3mm_P2.50mm
C4: 0.1uF; CP_Radial_D6.3mm_P2.50mm
C5: 4.7uF; CP_Radial_D6.3mm_P2.50mm
D1: LED 5mm RED; LED_D5.0mm_RED
D2: LED 5mm YELLOW; LED_D5.0mm_YELLOW
G2: LOGO
GRAPHICS2: LOGO
J1: DC-005 Power Jack
J2: PS/2 keyboard port; PS2-connector-keyboard
J3: RCA Video Jack
J4: Port B; PinHeader_1x07_P2.54mm_Vertical
J5: Port A; PinHeader_1x07_P2.54mm_Vertical
J6: Port C; PinHeader_1x08_P2.54mm_Vertical
J7: Port D; PinHeader_1x06_P2.54mm_Vertical
J8: USBasp header; PinHeader_2x05_P2.54mm_Vertical
J9: Power output header; PinHeader_2x04_P2.54mm_Vertical
MH1, MH2, MH3, MH4: MountingHole_3.2mm_M3_DIN965
R1, R5, R6: 10k; R_10k_Axial_DIN0207
R2, R3, R7, R8: 470R; R_470_Axial_DIN0207
R4: 1k; R_1k_Axial_DIN0207
S1: Button TACT 6x6mm
S2: Toggle Switch 7x7mm
S3: Slide Switch SS12D00
U1: ATmega1284P-P; DIP-40_W15.24mm
U2: L7805; TO-220-3_Vertical
U3: 25LC640; DIP-8_W7.62mm
Y1: 16 MHz; Crystal_HC49-U_Vertical

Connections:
+5V: C4.1, C5.1, J2.4, J9.1, J9.3, J9.5, J9.7, R1.1, R2.1, R5.1, R6.1, U1.10 (VCC), U1.30 (AVCC), U2.3 (OUT), U3.8 (VCC)
/POWER IN: J1.4, S2.5
/POWER IN 2: C3.1, S2.6, U2.1 (IN)
Clock: J2.5, U1.1 (PB0)
Data: J2.1, U1.14 (PD0)
GND: BZ1.2 (-), C1.2, C2.2, C3.2, C4.2, C5.2, D1.1 (K), D2.1 (K), J1.2, J1.3, J2.3, J2.S1, J2.S2, J2.S3, J3.1 (Shield), J8.4, J8.6, J8.8, J8.10, J9.2, J9.4, J9.6, J9.8, S1.3, U1.11 (GND), U1.31 (GND), U2.2 (GND), U3.4 (GND)
MISO: J4.6, J8.9, U1.7 (PB6), U3.2 (MISO)
MOSI: J4.5, J8.1, U1.6 (PB5), U3.5 (MOSI)
unnamed: BZ1.1 (+), R7.2
unnamed: D1.2 (A), R2.2
unnamed: D2.2 (A), R8.2
unnamed: J3.2 (Video), R3.1, R4.1
unnamed: J4.1, U1.2 (PB1)
unnamed: J4.2, U1.3 (PB2)
unnamed: J4.3, U1.4 (PB3)
unnamed: J5.1, U1.40 (PA0)
unnamed: J5.2, U1.39 (PA1)
unnamed: J5.3, U1.38 (PA2)
unnamed: J5.4, U1.37 (PA3)
unnamed: J5.5, U1.36 (PA4)
unnamed: J5.6, U1.35 (PA5)
unnamed: J5.7, U1.34 (PA6)
unnamed: J6.1, U1.22 (PC0)
unnamed: J6.2, U1.23 (PC1)
unnamed: J6.3, U1.24 (PC2)
unnamed: J6.4, U1.25 (PC3)
unnamed: J6.5, U1.26 (PC4)
unnamed: J6.6, U1.27 (PC5)
unnamed: J6.7, U1.28 (PC6)
unnamed: J6.8, U1.29 (PC7)
unnamed: J7.1, U1.15 (PD1)
unnamed: J7.2, U1.16 (PD2)
unnamed: J7.3, U1.17 (PD3)
unnamed: J7.4, U1.18 (PD4)
unnamed: J7.5, R8.1, U1.20 (PD6)
unnamed: J7.6, S3.1, U1.21 (PD7)
unnamed: R7.1, S3.2
unnamed: C2.1, U1.13 (XTAL1), Y1.2
unnamed: C1.1, U1.12 (XTAL2), Y1.1
unnamed: R5.2, U3.7 (~HOLD)
unnamed: R6.2, U3.3 (~WP)
RESET: J8.5, R1.2, S1.2, U1.9 (~RESET)
SCK: J4.7, J8.7, U1.8 (PB7), U3.6 (SCK)
Sync: R4.2, U1.19 (PD5)
Video: R3.2, U1.33 (PA7)
~CS: J4.4, U1.5 (PB4), U3.1 (~CS)

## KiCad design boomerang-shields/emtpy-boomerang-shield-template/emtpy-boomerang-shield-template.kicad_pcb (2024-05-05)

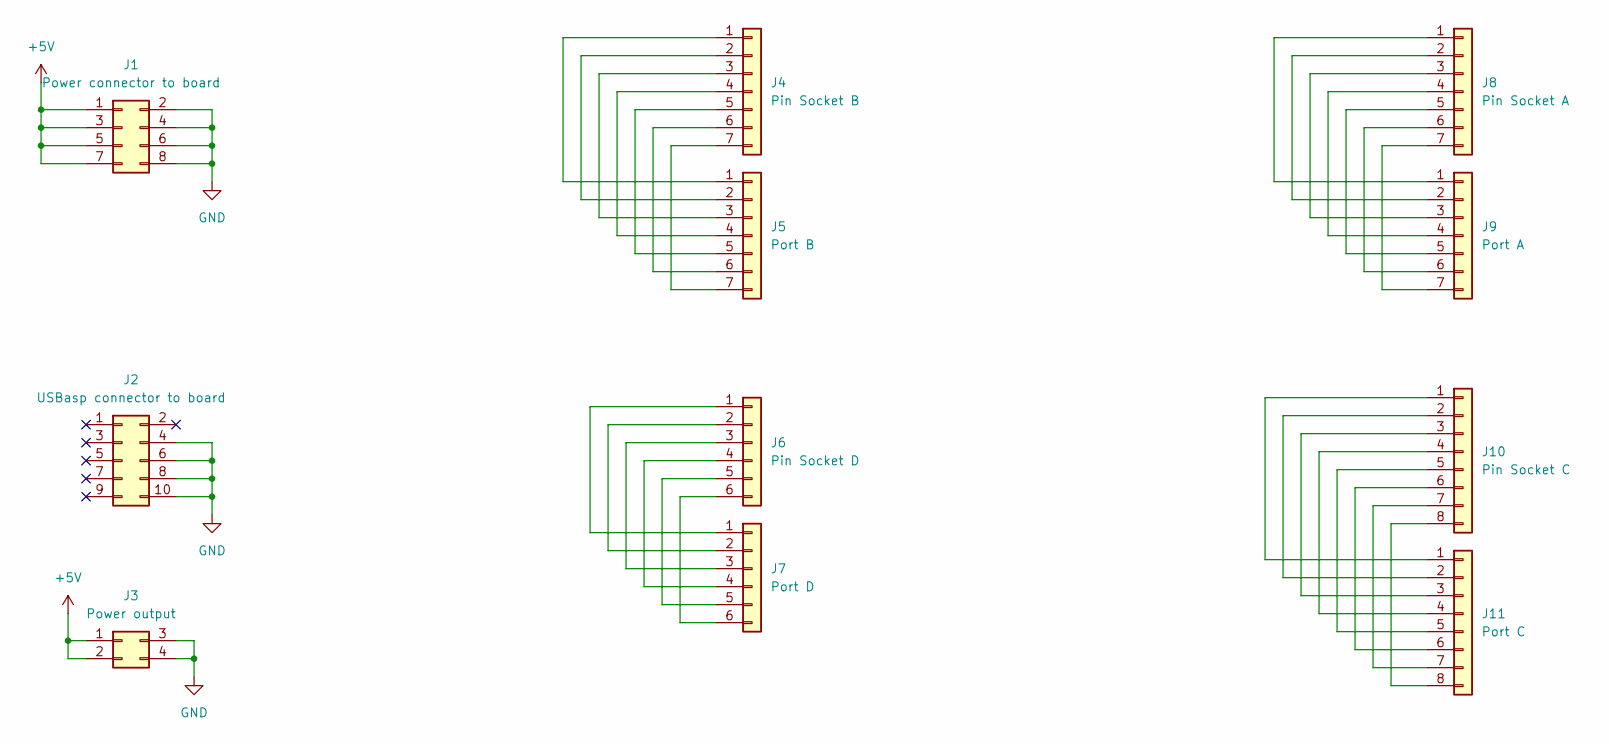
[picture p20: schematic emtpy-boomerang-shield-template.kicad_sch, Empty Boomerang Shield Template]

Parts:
J1: Power connector to board; PinHeader_2x04_P2.54mm_Vertical
J2: USBasp connector to board; PinHeader_2x05_P2.54mm_Vertical
J3: Power output; PinSocket_2x02_P2.54mm_Vertical
J4: Pin Socket B; PinSocket_1x07_P2.54mm_Vertical
J5: Port B; PinHeader_1x07_P2.54mm_Vertical
J6: Pin Socket D; PinSocket_1x06_P2.54mm_Vertical
J7: Port D; PinHeader_1x06_P2.54mm_Vertical
J8: Pin Socket A; PinSocket_1x07_P2.54mm_Vertical
J9: Port A; PinHeader_1x07_P2.54mm_Vertical
J10: Pin Socket C; PinSocket_1x08_P2.54mm_Vertical
J11: Port C; PinHeader_1x08_P2.54mm_Vertical

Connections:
+5V: J1.1, J1.3, J1.5, J1.7, J3.1, J3.2
GND: J1.2, J1.4, J1.6, J1.8, J2.4, J2.6, J2.8, J2.10, J3.3, J3.4
unnamed: J4.1, J5.1
unnamed: J4.2, J5.2
unnamed: J4.3, J5.3
unnamed: J4.4, J5.4
unnamed: J4.5, J5.5
unnamed: J4.6, J5.6
unnamed: J4.7, J5.7
unnamed: J6.1, J7.1
unnamed: J6.2, J7.2
unnamed: J6.3, J7.3
unnamed: J6.4, J7.4
unnamed: J6.5, J7.5
unnamed: J6.6, J7.6
unnamed: J8.1, J9.1
unnamed: J8.2, J9.2
unnamed: J8.3, J9.3
unnamed: J8.4, J9.4
unnamed: J8.5, J9.5
unnamed: J8.6, J9.6
unnamed: J8.7, J9.7
unnamed: J10.1, J11.1
unnamed: J10.2, J11.2
unnamed: J10.3, J11.3
unnamed: J10.4, J11.4
unnamed: J10.5, J11.5
unnamed: J10.6, J11.6
unnamed: J10.7, J11.7
unnamed: J10.8, J11.8

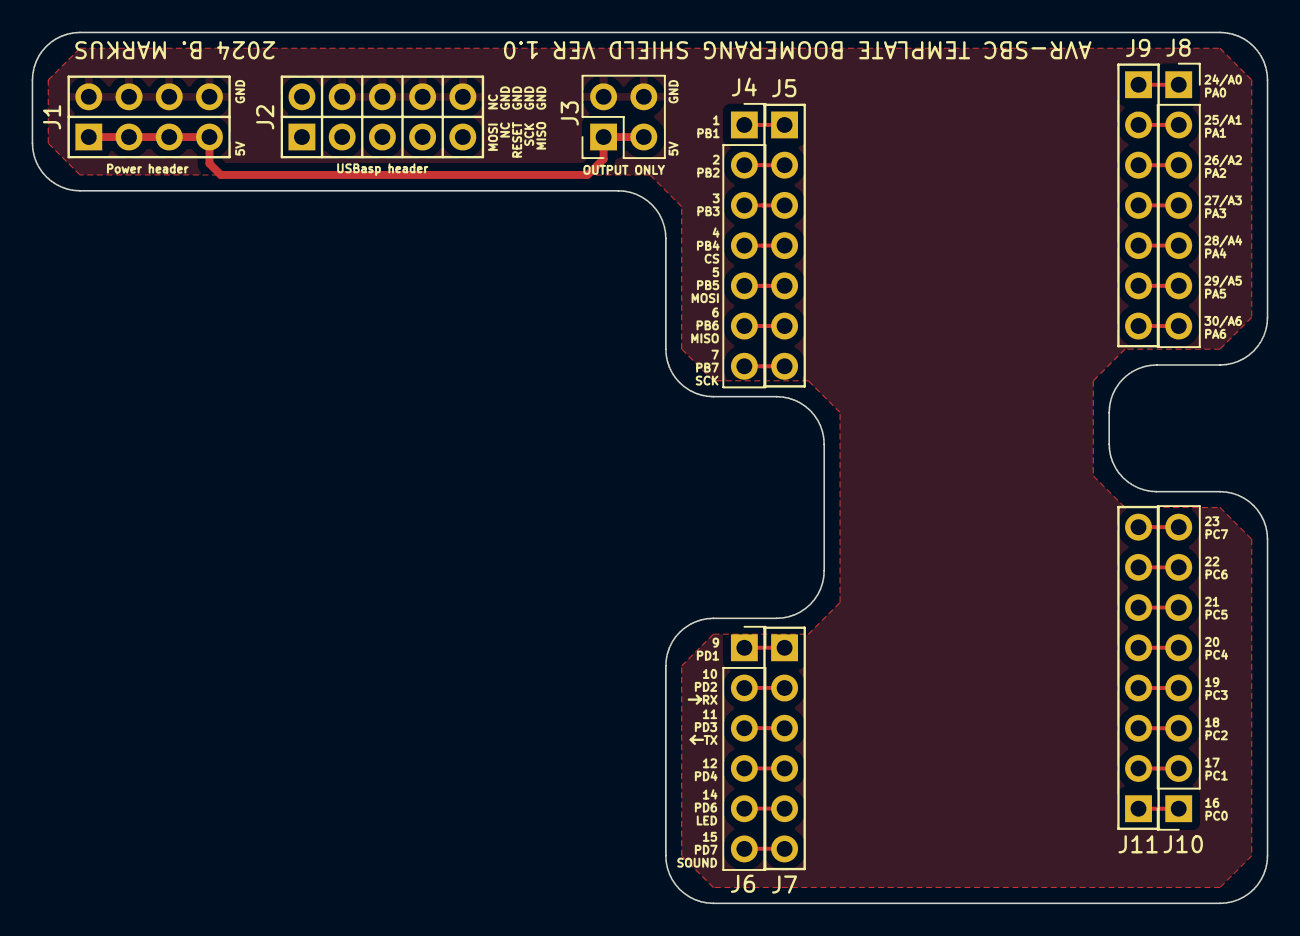
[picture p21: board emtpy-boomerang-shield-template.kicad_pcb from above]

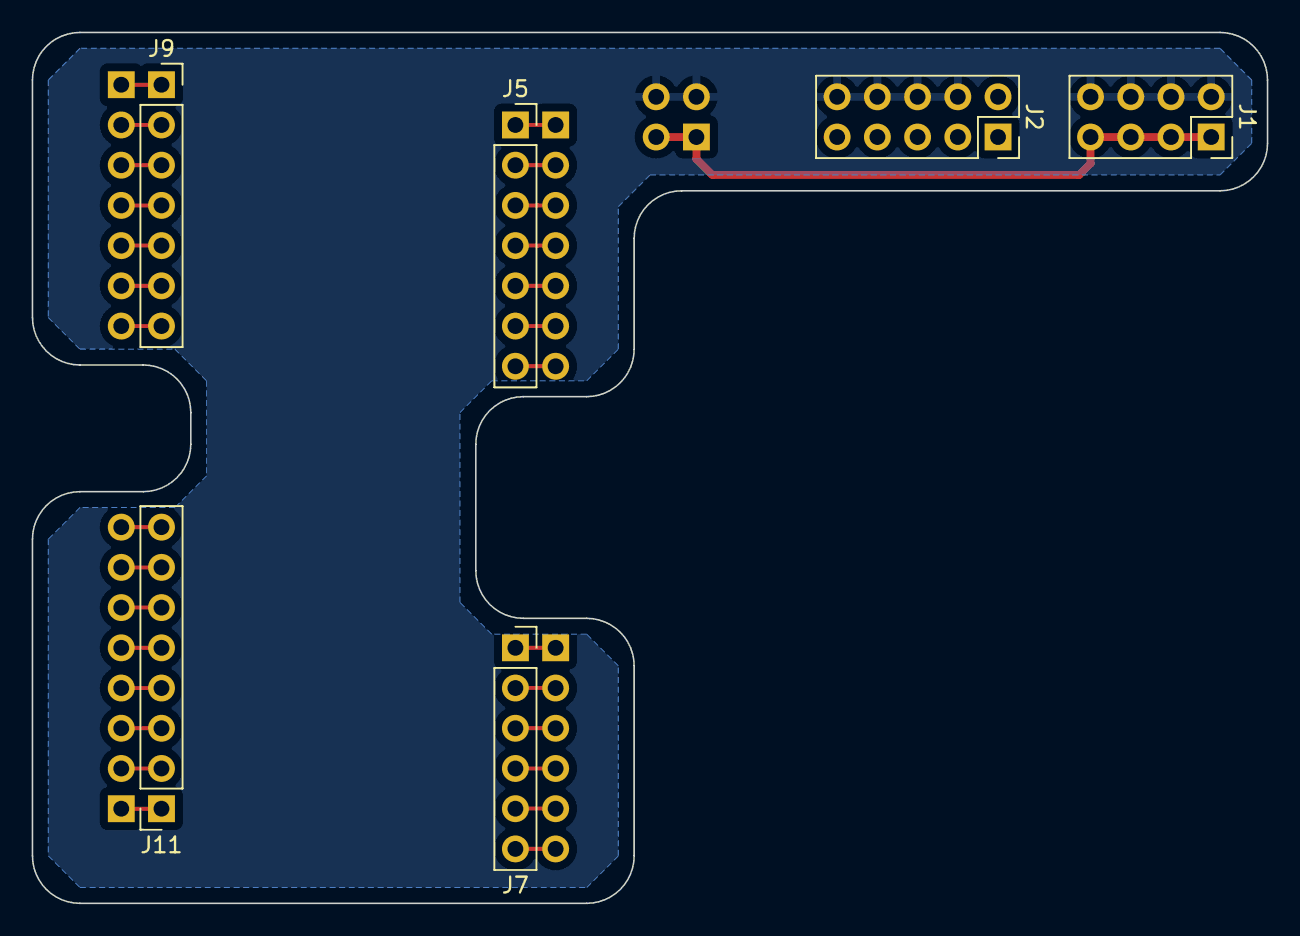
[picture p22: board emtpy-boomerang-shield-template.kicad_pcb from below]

Board: 2 copper layers, 78.0 x 55.0 mm, 11 parts (6 on the bottom side), 30 nets.

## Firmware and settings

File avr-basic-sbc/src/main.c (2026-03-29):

/*
 * main.c  --  ATmega1284P entry point for TinyBasicPlus bare-metal port
 *
 * Initialises video, keyboard, text subsystems, then hands control
 * to the BASIC interpreter.
 *
 * The interpreter blocks inside basic_init() -> basic_loop() which
 * contains its own input loop with cursor blinking.  If BYE is typed,
 * basic_init() returns, we clear the screen and restart.
 */

#include <avr/io.h>
#include <avr/interrupt.h>
#include "video.h"
#include "keyboard.h"
#include "text.h"
#include "basic_core.h"

int main(void)
{
    /* Initialise hardware */
    video_init();
    keyboard_init();
    text_init();

    sei();

    /* The interpreter blocks inside basic_init().
     * If BYE is executed, it returns and we restart. */
    while (1) {
        basic_init();

        /* If we get here, BYE was typed.  Re-init and restart. */
        text_cls();
    }
}

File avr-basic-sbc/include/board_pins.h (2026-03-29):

/*
 * board_pins.h  -  Hardware pin definitions for AVR-SBC v1.2
 *
 * Centralises all port/DDR/bit assignments so that changing the PCB layout
 * only requires editing this one file.  The BASIC interpreter accesses GPIO
 * through the AWRITE/DWRITE/AREAD/DREAD commands, which call the inline
 * helper functions defined at the bottom of this header.
 *
 * All assignments read directly from avr-basic-sbc.net (KiCad netlist).
 *
 * ============================================================
 * MightyCore Arduino-style pin number mapping
 * ============================================================
 *  Pin  Port/Bit  Notes
 *  ---  --------  -----------------------------------
 *   0   PB0       PS/2 keyboard clock  -- NOT AVAILABLE
 *   1   PB1       GPIO (J7)
 *   2   PB2       GPIO (J7)
 *   3   PB3       GPIO (J7)
 *   4   PB4       SPI /CS for EEPROM   -- shared with SPI
 *   5   PB5       SPI MOSI             -- shared with SPI
 *   6   PB6       SPI MISO             -- shared with SPI
 *   7   PB7       SPI SCK              -- shared with SPI
 *   8   PD0       PS/2 keyboard data   -- NOT AVAILABLE
 *   9   PD1       UART1 TX (J9)
 *  10   PD2       UART1 RX (J9)
 *  11   PD3       GPIO (J9)
 *  12   PD4       GPIO (J9)
 *  13   PD5       Video sync           -- NOT AVAILABLE
 *  14   PD6       Yellow LED (J9)
 *  15   PD7       Buzzer / OC2A
 *  16   PC0       GPIO (J8)
 *  17   PC1       GPIO (J8)
 *  18   PC2       GPIO (J8)
 *  19   PC3       GPIO (J8)
 *  20   PC4       GPIO (J8)
 *  21   PC5       GPIO (J8)
 *  22   PC6       GPIO (J8)
 *  23   PC7       GPIO (J8)
 *  24   PA0       GPIO (J6)
 *  25   PA1       GPIO (J6)
 *  26   PA2       GPIO (J6)
 *  27   PA3       GPIO (J6)
 *  28   PA4       GPIO (J6)
 *  29   PA5       GPIO (J6)
 *  30   PA6       GPIO (J6)
 *  31   PA7       Video data           -- NOT AVAILABLE
 *
 * ============================================================
 * SPI / 25LC640 External EEPROM (U3)
 * ============================================================
 *  MOSI    PB5 (pin 5)
 *  MISO    PB6 (pin 6)
 *  SCK     PB7 (pin 7)
 *  /CS     PB4 (pin 4)
 *
 * ============================================================
 * Buzzer / Piezo (BZ1)
 * ============================================================
 *  OC2A = PD7 (pin 15)  -> Timer2 CTC tone generation
 *
 * ============================================================
 * Video (J4 RCA)
 * ============================================================
 *  Video  -> PA7 (pin 31)
 *  Sync   -> PD5 (pin 13)
 *
 * ============================================================
 * PS/2 Keyboard (J2)
 * ============================================================
 *  Clock  -> PB0 (pin 0)
 *  Data   -> PD0 (pin 8)
 */
#ifndef BOARD_PINS_H
#define BOARD_PINS_H

#include <avr/io.h>

/* ------------------------------------------------------------------ */
/* Piezo / Buzzer  (BZ1 via R8 and slide-switch S3)                   */
/* OC2A on PD7 - Timer2 CTC toggles this pin for tone generation      */
/* ------------------------------------------------------------------ */
#define PIEZO_DDR    DDRD
#define PIEZO_PORT   PORTD
#define PIEZO_BIT    PD7

/* ------------------------------------------------------------------ */
/* SPI / 25LC640 external EEPROM (U3)                                 */
/* Hardware SPI on PB4(CS) PB5(MOSI) PB6(MISO) PB7(SCK)             */
/* ------------------------------------------------------------------ */
#define XEEP_CS_DDR   DDRB
#define XEEP_CS_PORT  PORTB
#define XEEP_CS_BIT   PB4

#define SPI_DDR       DDRB
#define SPI_PORT      PORTB
#define SPI_MOSI      PB5
#define SPI_MISO      PB6
#define SPI_SCK       PB7

/* Convenience macros */
#define XEEP_CS_LOW()   (XEEP_CS_PORT &= ~(1<<XEEP_CS_BIT))
#define XEEP_CS_HIGH()  (XEEP_CS_PORT |=  (1<<XEEP_CS_BIT))

/* ------------------------------------------------------------------ */
/* UART1  (PD2=RXD1, PD3=TXD1)                                       */
/* ------------------------------------------------------------------ */
#define UART1_BAUD_RATE   9600UL
#define UART1_UBRR_VAL    ((F_CPU / 16 / UART1_BAUD_RATE) - 1)

/* ------------------------------------------------------------------ */
/* Video  (PA7=data via R2-470R, PD5=sync via R3-1k)                  */
/* ------------------------------------------------------------------ */
#define VIDEO_DATA_PORT   PORTA
#define VIDEO_DATA_DDR    DDRA
#define VIDEO_DATA_BIT    PA7
#define VIDEO_SYNC_PORT   PORTD
#define VIDEO_SYNC_DDR    DDRD
#define VIDEO_SYNC_BIT    PD5

/* ------------------------------------------------------------------ */
/* PS/2 Keyboard  (PB0=Clock, PD0=Data)                               */
/* ------------------------------------------------------------------ */
#define KBD_CLK_DDR   DDRB
#define KBD_CLK_PORT  PORTB
#define KBD_CLK_PIN   PINB
#define KBD_CLK_BIT   PB0

#define KBD_DATA_DDR  DDRD
#define KBD_DATA_PORT PORTD
#define KBD_DATA_PIN  PIND
#define KBD_DATA_BIT  PD0
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

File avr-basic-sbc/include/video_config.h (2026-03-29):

/* video_config.h
 * Central configuration for the composite video signal generator.
 *
 * This file controls every timing, resolution, and pin-assignment
 * parameter that the video driver (video.c) and the graphics / text
 * layers depend on.  Adjust the values here to target a different
 * resolution, refresh standard (PAL/NTSC), or hardware pin layout.
 *
 * ---------------------------------------------------------------
 * QUICK-START: common changes
 *   Switch to NTSC  -> set LINES_PER_FRAME 262, DISPLAY_LINES 240
 *   Smaller image   -> reduce VRES and/or HRES_PIXELS (saves RAM)
 *   Shift image     -> tweak OUTPUT_START
 *   Different MCU   -> update F_CPU and recalculate cycle counts
 * ---------------------------------------------------------------
 */
#ifndef VIDEO_CONFIG_H
#define VIDEO_CONFIG_H

#include <stdint.h>

/* F_CPU: CPU clock frequency in Hz.
 * Must match the actual crystal/fuse setting of your ATmega.
 * The default is 16 MHz.  If your board runs at 8 MHz set this
 * to 8000000UL and recalculate LINE_CYCLES, HSYNC_CYCLES etc. */
#ifndef F_CPU
#define F_CPU 16000000UL
#endif

/* VIDEO_PORT / VIDEO_DDR / VIDEO_PIN_BIT
 * AVR port, DDR register, and bit number that drive the video DATA
 * signal.  On this board PA7 connects to the RCA jack via a 470 Ohm
 * resistor.  Change all three together if you rewire the video output. */
#define VIDEO_PORT      PORTA
#define VIDEO_DDR       DDRA
#define VIDEO_PIN_BIT   7
/* SYNC_PORT / SYNC_DDR / SYNC_PIN_BIT
 * AVR port, DDR register, and bit number that drive the composite SYNC
 * signal.  On this board PD5 connects via a 1 kOhm resistor.
 * Change all three together if you rewire the sync output. */
#define SYNC_PORT       PORTD
#define SYNC_DDR        DDRD
#define SYNC_PIN_BIT    5
/* LINE_CYCLES: Timer1 counts per complete scan line.
 * At 16 MHz one count = 62.5 ns, so 1024 counts = 64 us (PAL line period).
 * Do NOT change this without also retuning HSYNC_CYCLES and VSYNC_CYCLES. */
#define LINE_CYCLES     1024
/* HSYNC_CYCLES: Timer1 counts for the horizontal sync pulse width.
 * 74 counts at 16 MHz ≈ 4.625 us (PAL spec: 4.7 us).
 * Increase to widen the pulse; decrease to narrow it.
 * Too far in either direction will cause the monitor to lose sync. */
#define HSYNC_CYCLES    74
/* VSYNC_CYCLES: OCR1A reload value during the vertical sync interval.
 * Controls how wide the vsync pulse is across the equalising/sync lines.
 * Tune together with VSYNC_END if the picture rolls vertically. */
#define VSYNC_CYCLES    940
/* OUTPUT_START: Timer1 low-byte threshold at which pixel output begins
 * on each active scan line.  This is the primary horizontal-position
 * control:
 *   Increase -> image shifts RIGHT  (later start)
 *   Decrease -> image shifts LEFT   (earlier start)
 * Valid range: 0-255.  Default 199 works well for most PAL monitors. */
#define OUTPUT_START    199
/* HRES_PIXELS: Horizontal resolution in pixels.
 * Must be a multiple of 8 (one byte = 8 pixels in the framebuffer).
 * Increasing this requires more SRAM and a faster pixel-output ISR.
 * Common values: 160, 240, 320. */
#define HRES_PIXELS     320
/* HRES_BYTES: Bytes per framebuffer row (derived, do not set manually).
 * = HRES_PIXELS / 8  because the framebuffer stores 1 bit per pixel. */
#define HRES_BYTES      (HRES_PIXELS / 8)
/* VRES: Vertical resolution in pixel rows stored in the framebuffer.
 * The hardware will repeat each row (vscale+1) times to fill DISPLAY_LINES.
 * Increasing VRES costs SRAM; maximum is DISPLAY_LINES / (vscale+1). */
#define VRES            240
/* FB_SIZE: Total framebuffer size in bytes (derived, do not set manually).
 * = HRES_BYTES x VRES.  At 320x240 this is 9600 bytes of SRAM.
 * Check that FB_SIZE + kRamSize (BASIC buffer, ~5500) fits in 16 KB. */
#define FB_SIZE         ((uint16_t)HRES_BYTES * VRES)
/* TEXT_COLS / TEXT_ROWS: Text terminal dimensions (derived, do not set manually).
 * One character cell = 8x8 pixels.  At 320x240: 40 columns, 30 rows. */
#define TEXT_COLS       (HRES_PIXELS / 8)
#define TEXT_ROWS       (VRES / 8)
/* LINES_PER_FRAME: Total scan lines per video frame.
 * PAL  = 312  (50 Hz, used in Europe)
 * NTSC = 262  (60 Hz, used in North America / Japan)
 * Switching to NTSC: set 262 and also reduce DISPLAY_LINES to 240. */
#define LINES_PER_FRAME 312
/* VSYNC_END: Scan line index at which the vsync pulse ends and the
 * back-porch / blank region begins.  PAL value = 7.
 * Adjust if your monitor shows a partial frame at the top. */
#define VSYNC_END       7
/* DISPLAY_LINES: Number of scan lines in the active display window.
 * The framebuffer is vertically centred within this window.
 * Constraint: DISPLAY_LINES >= VRES * (DISPLAY_LINES/VRES).
 * For NTSC set this to 240. */
#define DISPLAY_LINES   260
/* ACTIVE_START: First scan line of the active video area (top of image).
 * Used only in centring calculations; changing it shifts the image up/down.
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

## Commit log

2024-03-07 Schematics and PCB design files added
    [avr-basic-sbc-B_Cu.gbr, avr-basic-sbc-B_Mask.gbr, avr-basic-sbc-B_Paste.gbr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]
2024-04-03 PCB Version v1.1 - AV Video RCA Jack polarity reversed, silkscreen updates
    [avr-basic-sbc-B_Cu.gbr, avr-basic-sbc-B_Mask.gbr, avr-basic-sbc-B_Paste.gbr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]
2024-04-04 Serial Boomerang Shield schematic + PCB added
    [serial-boomerang-shield.kicad_pcb, serial-boomerang-shield.kicad_sch]
2024-04-04 Serial Boomerang Shield updated + Gerber files generated
    [serial-boomerang-shield-B_Cu.gbr, serial-boomerang-shield-B_Mask.gbr, serial-boomerang-shield-B_Paste.gbr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]
2024-04-05 Serial Boomerang Shield updated, power output header added
    [serial-boomerang-shield.kicad_pcb, serial-boomerang-shield.kicad_sch]
2024-04-05 AVR-SBC board updated - USBasp header realigned to match 0.254mm grid
    [avr-basic-sbc-B_Cu.gbr, avr-basic-sbc-B_Mask.gbr, avr-basic-sbc-B_Paste.gbr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]
2024-04-05 AVR-SBC board updated - Power header realigned to match 0.254mm grid
    [avr-basic-sbc-B_Cu.gbr, avr-basic-sbc-B_Mask.gbr, avr-basic-sbc-B_Paste.gbr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]
2024-04-05 Serial Boomerang Shield updated - Power header realigned to match 0.254mm grid
    [serial-boomerang-shield.kicad_pcb]
2024-04-05 AVR-SBC board updated - GPIO headers and IC-s realigned to match 0.254mm grid
    [avr-basic-sbc-B_Cu.gbr, avr-basic-sbc-B_Mask.gbr, avr-basic-sbc-B_Paste.gbr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]
2024-04-05 Serial Boomerang Shield updated - GPIO headers realigned to match 0.254mm grid
    [serial-boomerang-shield-B_Cu.gbr, serial-boomerang-shield-B_Mask.gbr, serial-boomerang-shield-B_Paste.gbr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]
2024-04-05 AVR-SBC board updated - Silkscreen updates and fill zones updated to match 1mm grid
    [avr-basic-sbc-B_Cu.gbr, avr-basic-sbc-B_Mask.gbr, avr-basic-sbc-B_Paste.gbr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]
2024-04-05 Serial Boomerang Shield schematic PDF added
2024-04-05 AVR-SBC board updated - Mounting holes aligned to match 1mm grid
    [avr-basic-sbc-B_Cu.gbr, avr-basic-sbc-B_Mask.gbr, avr-basic-sbc-B_Paste.gbr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]
2024-04-09 AVR-SBC board updated: Connectors moved closer to each other to leave space for shields
    [avr-basic-sbc-B_Cu.gbr, avr-basic-sbc-B_Mask.gbr, avr-basic-sbc-B_Paste.gbr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]
2024-04-09 AVR-SBC board updated: Silkscreen version number updated
    [avr-basic-sbc-B_Cu.gbr, avr-basic-sbc-B_Mask.gbr, avr-basic-sbc-B_Paste.gbr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]
2024-04-16 AVR-SBC board updated: Silkscreen updated
    [avr-basic-sbc-B_Cu.gbr, avr-basic-sbc-B_Mask.gbr, avr-basic-sbc-B_Paste.gbr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]
2024-05-03 AVR-SBC code updated: SERREAD prints only human-readable ASCII characters
2024-05-04 AVR-SBC code updated: Print statements updated
2024-05-05 Empty boomerang shield template added as a base to develop projects on
    [emtpy-boomerang-shield-template.kicad_pcb, emtpy-boomerang-shield-template.kicad_sch]
2024-05-05 AVR-SBC board schematic rearranged to make it look nicer, PDF regenerated
    [avr-basic-sbc.kicad_sch]
2024-05-05 Schematic folder: gitignore updated
2024-05-05 KiCad gitignore added to boomerang shields
2026-03-05 Schematic: Update to v1.3, schottky diode added to ISP header for protection, decoupling capacitors added
    [avr-basic-sbc.kicad_pcb, avr-basic-sbc.kicad_sch]
2026-03-18 PCB updated
    [avr-basic-sbc.kicad_pcb]
2026-03-26 PCB reverted to release version v1.2
    [avr-basic-sbc.kicad_pcb, avr-basic-sbc.kicad_sch]
2026-03-29 Schematic migrated to KiCad 9, image added to docs/images
    [avr-basic-sbc.kicad_pcb, avr-basic-sbc.kicad_sch]
